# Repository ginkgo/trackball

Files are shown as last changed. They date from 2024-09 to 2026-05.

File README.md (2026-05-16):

# Trackball

## News

- 2026-05-15: Added experimental firmware support for using the trackball as a 3D space mouse. [More info here.](ndof.md)
- 2025-12-25: I'm releasing a new version (Mk.II) that should be easier to print and build.

## Introduction

This is a 3d-printable twist-to-scroll trackball using a Raspberry Pi Pico and two PMW3360 sensors designed using [build123d](https://github.com/gumyr/build123d).

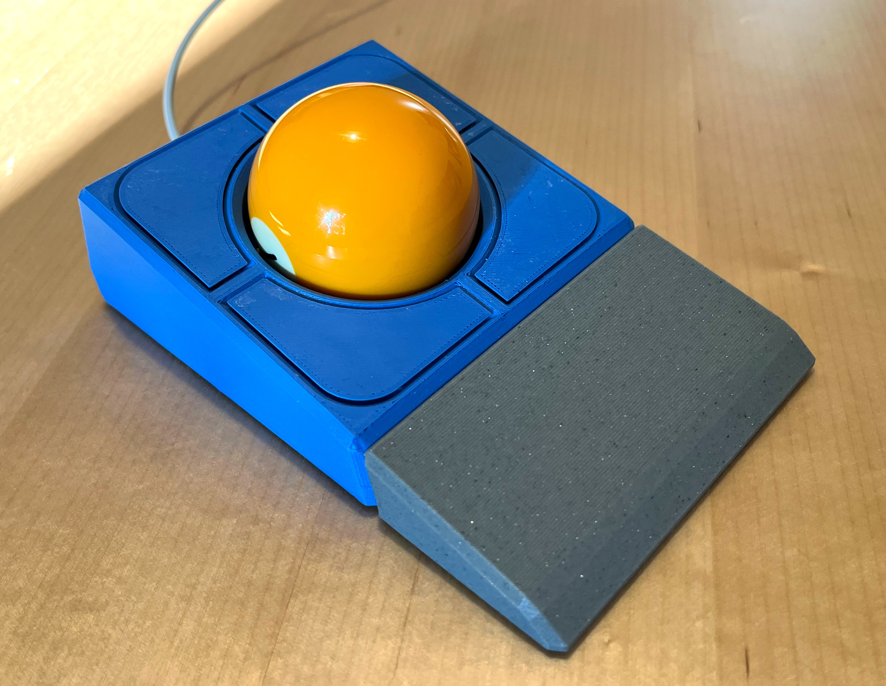
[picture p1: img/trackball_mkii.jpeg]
Trackball Mk.II


## Build Instructions

You can find build instructions for the latest version here: [Mk.II Build Instructions](trackball_mkii.md)

In case you're interested in the original version you can find it [here](trackball_mki.md).

## General Info

It's based on [jfedor2](https://github.com/jfedor2)'s excellent set of projects.
In particular it's using 2 [PMW3360 breakout PCBs](https://github.com/jfedor2/pmw3360-breakout) and 4 [mouse buttons switch mount PCBs](https://github.com/jfedor2/mouse-switch-mount-pcb). It's also using a firmware derived from his [twist-to-scroll trackball](https://github.com/jfedor2/twist-to-scroll-trackball) project.

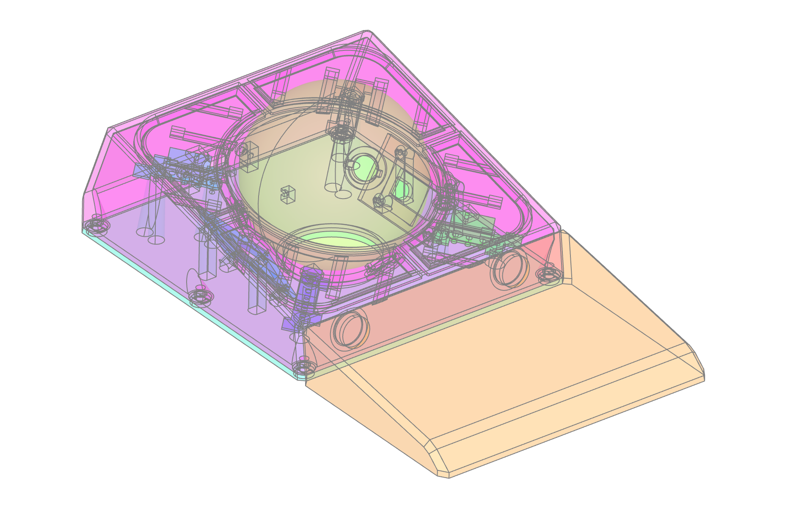
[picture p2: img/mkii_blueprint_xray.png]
Mk.II blueprint


However there's a number of pretty major changes:

Instead of a [RP2040+PMW3360](https://github.com/jfedor2/rp2040-pmw3360) board I'm using a regular Raspberry Pi Pico.

I redesigned the entire enclosure from the ground up in build123d. The nice thing about this is that it should be possible to parameterize the generated model (for instance to use a 55mm trackball instead of a 57.2mm billiards ball or to change the type of bearing used).

The button assembly is quite different and feels a lot better in my opinion.

The sensors are arranged at a 45-degree angle to move them as low as possible and keep them out of the way of the button assembly.
This means when reading from the sensors, some axis values (the X and Z axis) need to be reconstructed from a combination values from both sensors.

This is done in firmware. The basic math isn't too complicated, but it meant that the time delay between reading both sensors should be minimal or else the time lag might show up as unintended twists around the Z axis.
To improve this I interleaved the sensor access. I also switched from RP2040 HW SPI to PIO SPI which allowed for more flexible GPIO mapping.

## Experience

The Mk.II version is significantly easier to build and the button reach and feel is better.
Honestly it's an all-around better design.

<video src="img/mkii_in_action.mp4" width="480" height="480" controls></video>
The Mk.II trackball in action

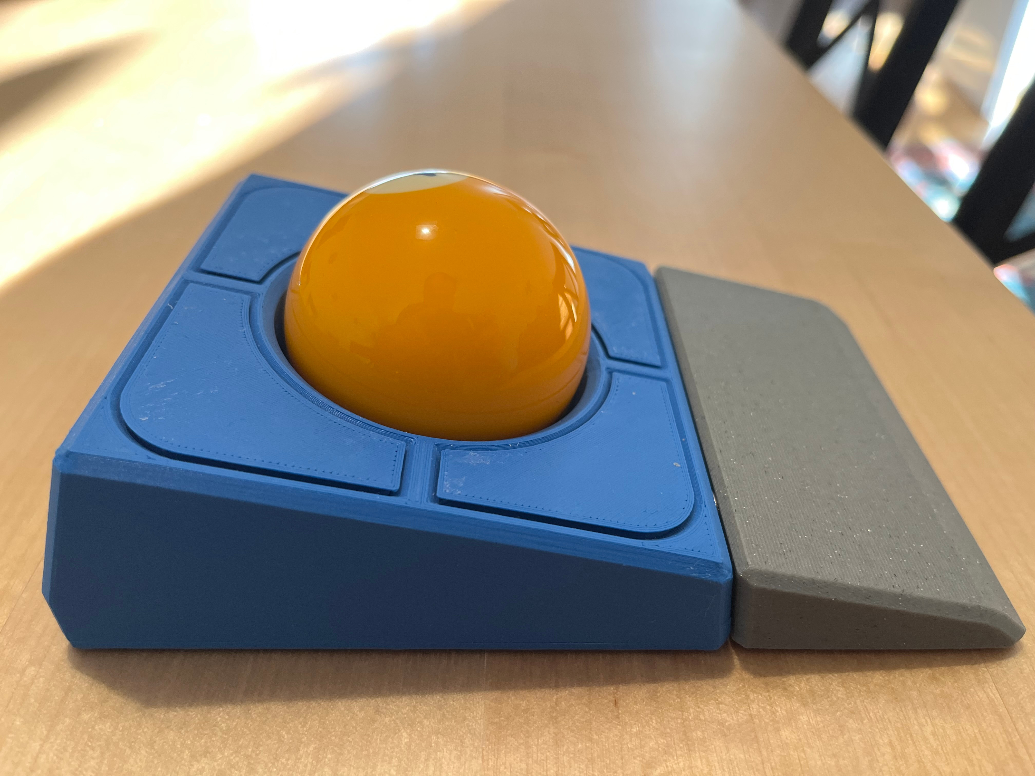
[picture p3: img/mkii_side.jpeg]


## Future Ideas

My next big project will be a combined keyboard+trackball device. This will likely live in a separate github project though.

I'd like to make a magnetically attached top cover for easy transport.

The firmware could need quite a bit of cleanup.
Alternatively adding support for this trackball in QMK might also be an option.
I've created a [rough patch to QMK](https://github.com/ginkgo/qmk_firmware/tree/trackball) but this will need to be reworked to get it merged upstream. It'll also need changes to how sensors are connected to the SoC.

Using PIO it should be possible to access both sensors in perfect lock-step by having them share a single SCLK, NCS, and MOSI pin and having two separate MISO pins that are read at once.

## Support

If you need help with building this then you can reach me on the [/r/trackballs](https://discord.gg/772eGUxAUb) Discord server.
Alternatively you can also create a discussion thread here.

If you have suggestions for improvements feel free to open an issue or create a pull request.

## License

The 3d-printable parts as well as the python code to generate them is copyright 2024-2026 Thomas Weber and licensed under terms the MIT license.

The firmware is copyright 2024-2026 Thomas Weber, copyright 2021 Jacek Fedoryński (jfedor2), and copyright 2019 Ha Thach (tinyusb.org) and licensed under the terms of the MIT license.
There is also a piece of code for the SPI PIO copyright 2020 of the Raspberry Pi that's licensed under the terms of the BSD-3-Clause license.

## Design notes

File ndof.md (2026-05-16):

# Experimental 3D Space Mouse Mode

I recently added support in firmware that allows using the trackball as a space mouse for full 3 axis rotations.

This requires building a separate firmware version for now. In principle it should be possible for one firmware build to support both trackball and space mouse mode and switching between them on the fly but that's not implemented yet.

I've only tested this on Linux with [spacenavd](http://github.com/FreeSpacenav/spacenavd) so far.

## Building the firmware

Follow the general firmware build instructions, but add the `-DDEVICETYPE=SPACEMOUSE` option when configuring.

```
cd firmware
mkdir build
cd build
cmake .. -DBOARD=<board_type> -DTRACKBALL=<trackball_version> -DDEVICETYPE=SPACEMOUSE
make -j8
```

This generates a `trackball.uf2` which you can upload to your board.

## Using the Device

Install `spacenavd` and add the following config option to `/etc/spnavrc`:

```
device-id = cafe:ba3d
```

This is the dummy USB device ID reported by the trackball in spacemouse mode.
Then start the `spacenavd` daemon.

With this any software that supports `libspnav` should now allow you to control rotations using the trackball. I've tested Blender and FreeCAD and they work.
You probably need to tune sensitivity and swap some axes depending on the used application. You can do that with the `spnavcfg` tool.

Blender by default locks the rotation of one axis. To fix this change the 'Orbit Method' from 'Turntable' to 'Trackball' under 'Navigation' in the Preferences.

FreeCAD needs "Swap Y-Z" enabled and RY inverted in spnavcfg. It also needs to have the sensitivity lowered significantly.

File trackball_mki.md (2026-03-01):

# Trackball Mk.I

This is the first version of my DIY trackball. 

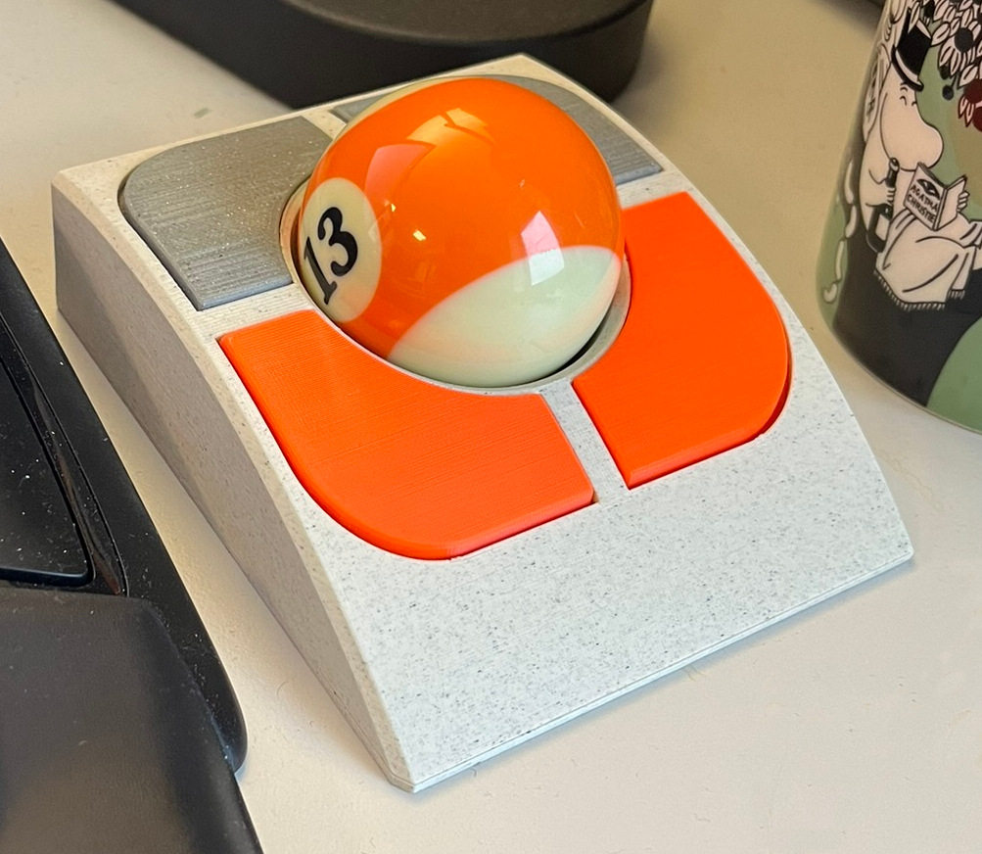
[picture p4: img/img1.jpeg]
Trackball Mk.I


It's significantly different from the second version ([Mk.II](trackball_mkii.md)) which completely redesigned the outer housing.
Personally I think the new version is just overall easier to build and nicer to use but I'm keeping this for posterity.

The old design requires a lot more individual parts that need to be printed and screwed together. On the plus side it's possible to use a regular RaspberryPi Pico board:

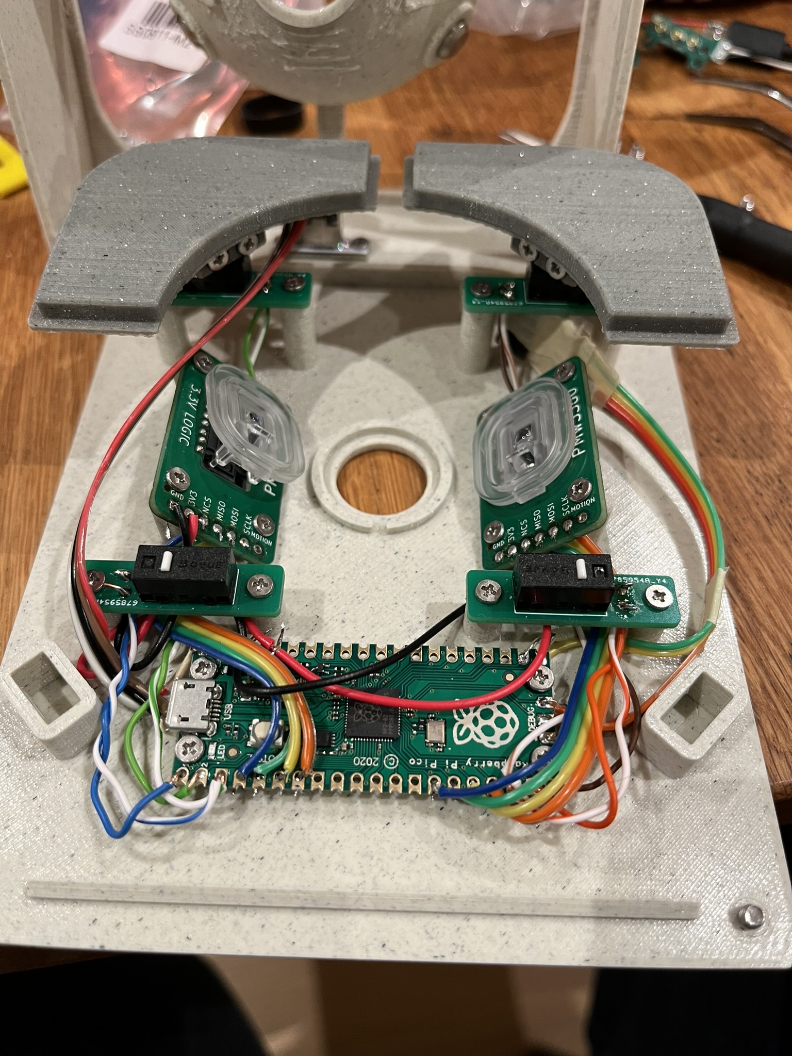
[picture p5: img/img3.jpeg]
opened trackball


## Getting started

You can download tarballs with pregenerated parts and firmware under "Releases". 
If you want to do this yourself you can find details further below.

The Mk.I model allows a bunch of possible configurations regarding what size ball to use and what kind of switch and MCU PCBs to use.

## 3D printing
These are the parts you need to print:

* `bottom`
  * The base plate for the entire assembly. Doesn't need supports.
* `top`
  * The top cover of the trackball. Needs supports.
* `button0`, `button1`, `button2`, `button3`
  * The top buttons. Each one has a different curvature so they're not interchangeable. Need supports.
* `strip0`, `strip1`, `strip2`, `strip3`
  * The flexible springs to hold the button in place. You need 4 of these but they come in identical pairs (two shorter ones for the front and two longer ones for the back). Doesn't need supports when printed on the side.
* `adapter_X.Ymm` (optional)
  * Adapter if you want to use a static bearing to hold the trackball (instead of a BTU)
  * The `X.Ymm` number is the diameter of the bearing. So for instance `adapter_2.5mm` is for 2.5mm bearing balls.

I printed everything with PLA and a layer size of 0.1mm.

The printed models shouldn't need too much cleanup apart from the contact surface between the buttons and the underside of the top cover.
Any residue supports must be removed. I found this area also needs a bit of manual filing and adjustment until the button clickiness feels right.
I used needle files for this.

## Parts

Apart from the 3d-printed parts you need the following:

* 1 microcontroller board. Either:
  * A RaspberryPi Pico
    This should be easy to find but you will need to do some extra soldering for the USB cable.
  * A [RP2040 Supermini](https://www.eelectronicparts.com/products/rp2040-super-mini-pico-compatible-with-raspberry-pi-micro-python-2mb-flash)
    This plugs directly into the USB socket in the back of the trackball so less soldering necessary.
	`--cable-mount-type RP2040_SUPERMINI`
* 2 [PMW3360 breakout PCBs](https://github.com/jfedor2/pmw3360-breakout) with a PMW3360 sensor soldered in.
  These will need to be ordered from a service like JLCPCB or PCBWay. You will find the Gerber files and BOM on jfedor's github.
* 4 keyswitch mount PCBs with a D2F type switch. You have two options here:
  * Custom order jfedor's [mouse switch mount PCB](https://github.com/jfedor2/mouse-switch-mount-pcb)
    `--switch_pcb_type JFEDOR2`
  * Buy 2 pairs of [G304/G305 button replacement PCBs](https://vi.aliexpress.com/item/1005004663221786.html).
    `--switch_pcb_type G304`
* 1 57.2mm billiards ball
  * Or a 55mm trackball if you adjust the ball size in the script
* 3 YK310 type BTUs (or steel/ruby/ceramic bearings with an adapter)
* 4 10x2mm cylindric neodymium magnets (for attaching wrist-rest in Mk.II)
  * The magnets in the main unit can also be thicker
* Machine screws
  * M3x4 (For bottom screws)
  * M2x3 (For almost everything else)
  * M1.6x3 (In case you use G304/G305 button PCBs)
* A [USB-C socket](https://vi.aliexpress.com/item/1005007593502706.html)
  * in case you use a RaspberryPi Pico board.
* Various cabling and solder supplies
  * I recommend getting pairs of JST male/female cables so breakout boards can be attached after soldering.
* Some adhesive rubber feet or strips so the trackball doesn't slip.

## Wiring

Here's some rough wiring diagrams for both board configurations.
You can change the GPIO pins used in `firmware/src/trackball.cc` if you want to move things around.

I recommend using JST cables to connect the microcontroller and the breakout boards.

### Wiring (RaspberryPi Pico)
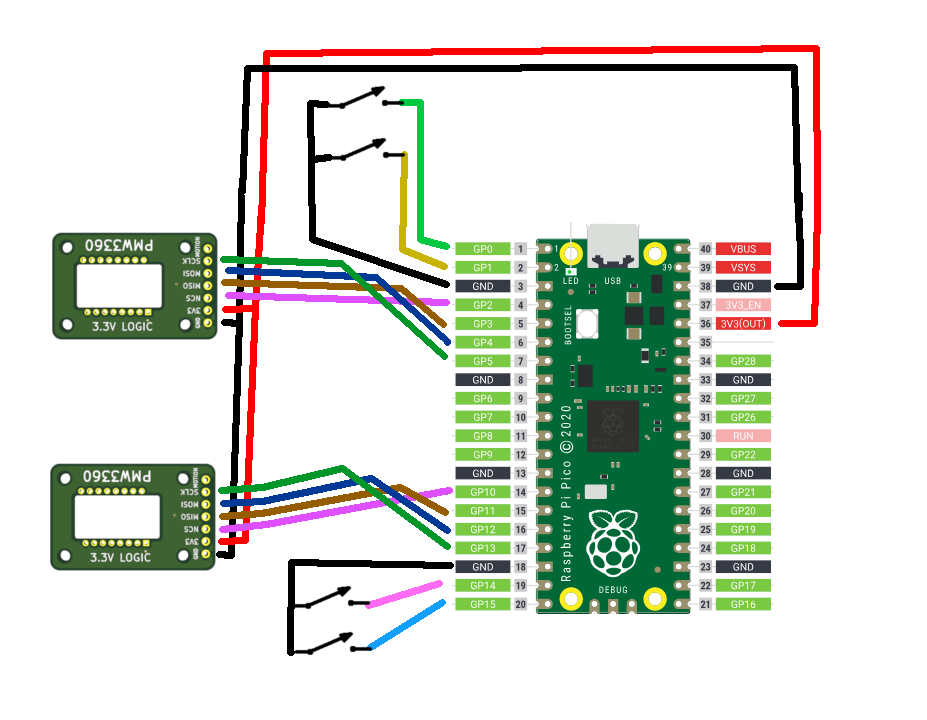
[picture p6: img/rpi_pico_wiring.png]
RaspberryPi Pico wiring diagram


### Wiring (RP2040 Supermini)
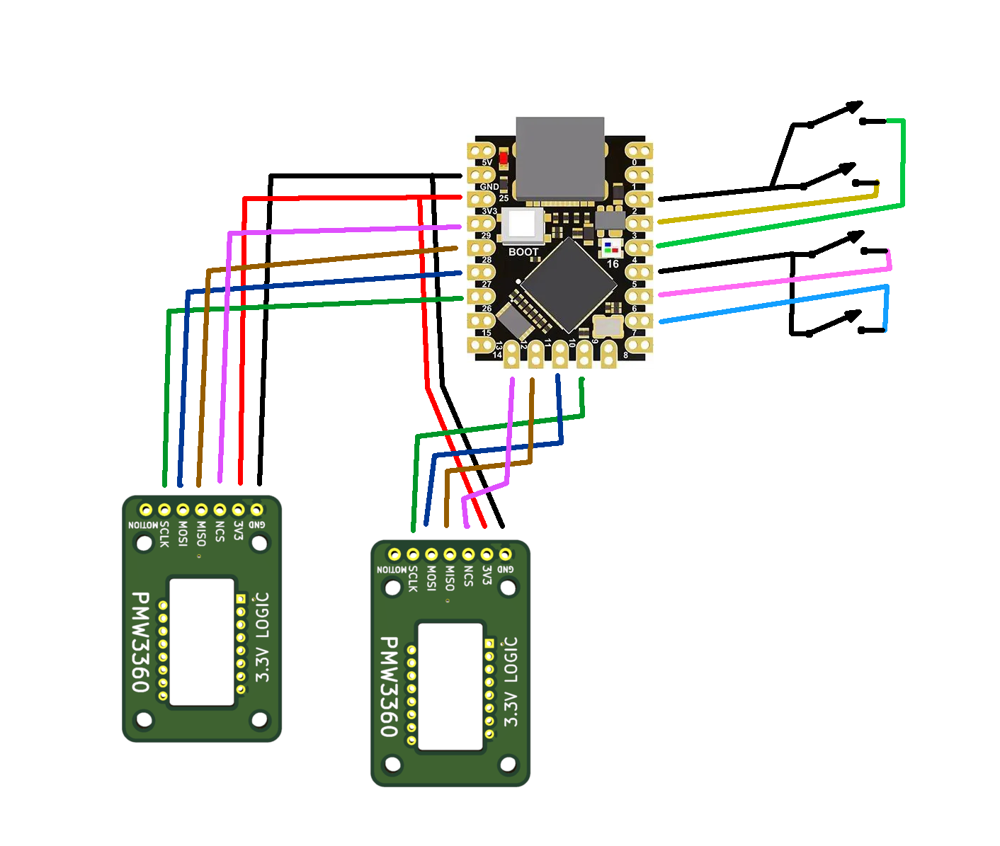
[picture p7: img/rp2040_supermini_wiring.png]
RP2040 Supermini wiring diagram


## Assembly

Once you printed out your parts and wired everything up you should be ready to assemble your trackball.
This should hopefully be relatively straightforward.

* Screw the various boards to the bottom plate.
* Screw flexible strips to the button parts and place the assembled buttons over the switches.
* Place the top part over everything and secure it with the screws on the bottom (and back).
* Push in your bearing of choice.

You can open all the model files in a 3d editor like blender to see where everything goes.

The bit that's probably easiest to mix up is which button goes where. The best way to tell which is which is to look at their curvature. Front buttons have a much steeper angle and the lowest part protudes below the attachment point for the flexible strip.
You should also be able to tell by the layer lines from the 3d print.

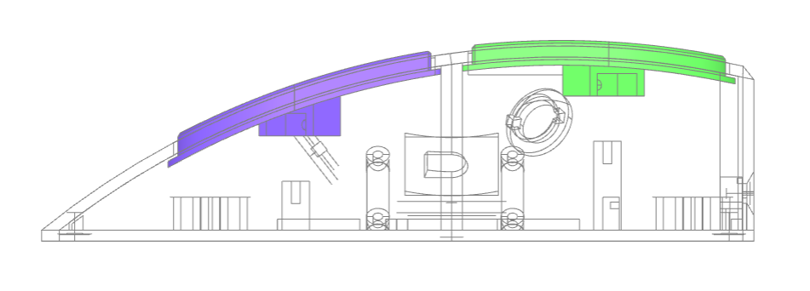
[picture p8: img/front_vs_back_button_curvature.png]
front vs back buttons


## Minor tips and tricks

The trackball can be configured to either use ball transfer units (7.5mm [YK310 or YK311](https://www.aliexpress.com/item/1005005528750648.html) type from aliexpress) or have small indentations to press in small steel or zirconium bearing balls.

However I found it's most flexible to just adapt an enclosure for ball transfer units to bearing balls using a small 3d-printed adapter.

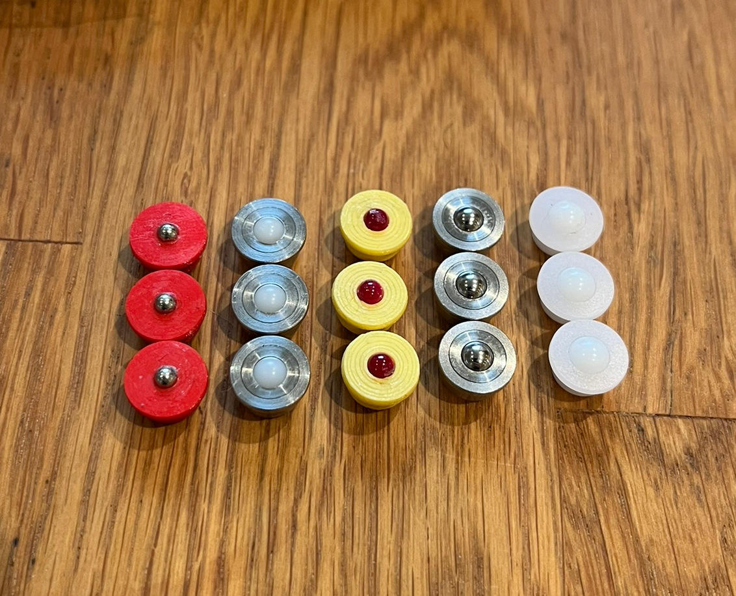
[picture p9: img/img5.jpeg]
different ball transfer units and bearing ball adapters


You can find the pregenerated models for the adapter in the `stl` and `step` folders and the script to generate it in `adapter.py`.

## Experience

I've been using the Mk.I trackball for about a year now. Initially I was kind of struggling finding a type of bearing I like.
At least the cheap BTUs didn't quite feel right. I ended up with using static ruby bearings for my current setup which I tend to like best.
The pool balls I'm using aren't the highest quality and noticeable uneven in places. I should eventually try to get something better. (I ordered a set of Kandy Pearlized balls that got recommended, but these didn't seem to work with my PMW3360 sensors)

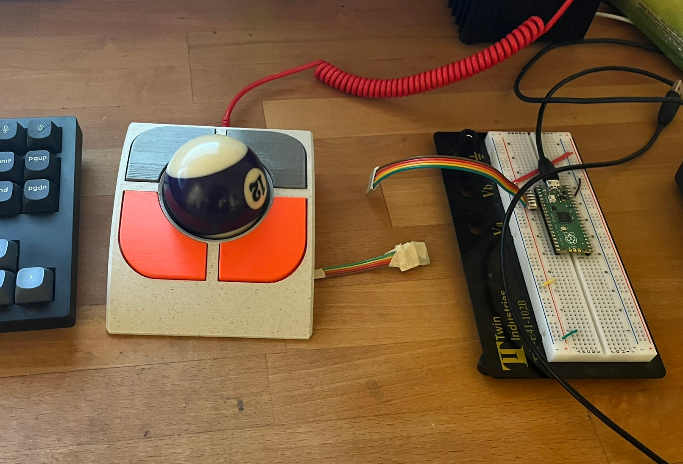
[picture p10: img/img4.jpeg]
my home setup

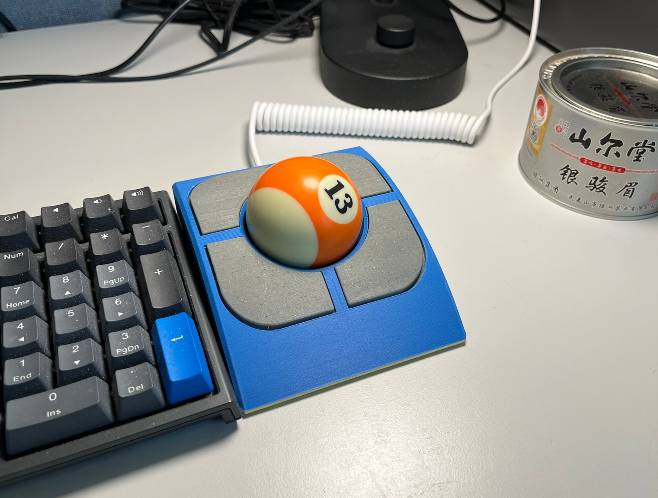
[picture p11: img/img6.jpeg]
my work setup


In principle it should be possible to CNC machine all parts for the Mk.I trackball in metal. (Mk.II is trickier) This would likely need a bit of cleanup to some parts but nothing major.

One persistent problem the Mk.I has is that the front buttons tend to get stuck when you click them. This can be "improved" by filing down the underside of the enclosure, but that leads to loose buttons. Theoretically the proper fix would be to change the angle in which the buttons protrude, but I ended up going for a complete revamp with the Mk.II instead.

## Configuring and generating the models

The enclosure parts are generated by the `trackball.py` script.
They use `build123d` and I generally recommend using `uv` to run them like this:
You can generate the `STL` or `STEP` files by calling

```
$ uv run --with build123d trackball.py --step --outdir mk1
```

This generates `.step` model files in the `mk1` subdir.
You can also use PyPI or Conda to install `build123d` instead.

There's more configuration options. Call the scripts with `--help` for details.

## Building the firmware

To build the firmware you need to have `pico-sdk` installed.
Then configure and build using CMake:

```
cd firmware
mkdir build
cd build
cmake .. -DBOARD=<board_type> -DTRACKBALL=<trackball_version>
make -j8
```

This generates a `trackball.uf2` which you can upload to your board.

`<board_type>` is the type of microcontroller board you want to target. Possible options are `RPI_PICO` for a regular RaspberryPi Pico or `RP2040_SUPERMINI` for a RP2040 supermini board.
`<trackball_version>` is the version of the trackball to generate. This is either `MK_I` for the Mk.I version or `MK_II` for the Mk.II version.

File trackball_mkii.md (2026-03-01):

# Trackball Mk.II

This is the latest version of my DIY trackball. 

Trackball Mk.II

This version is designed so that the entire top assembly including buttons can be printed upside down in one piece. That way what used to be 9 parts that were somewhat fiddly to screw together and assemble are now a single easy to print part.
No support material should be needed for printing either.

Personally I feel like this is the allround better design. Use this unless you really like the look of the old version.

## Getting started

You can download tarballs with pregenerated parts and firmware under "Releases". 
If you want to do this yourself you can find details further below.

## 3D printing
There's only two parts that need to be printed (`bottom` and `top`). The rest are optional.

None should need support materials but a spot or two of organic supports for the openings in the bowl of the `top` part might result in cleaner prints.

* `top`
  * The top cover and button assembly. This should be printed upside-down placed on its flat top surface.
* `bottom`
  * The base plate for the assembly
* `wrist_rest` (optional)
  * This is an optional wrist-rest that attaches to the main unit with neodymium magnets.
* `adapter_X.Ymm` (optional)
  * Adapter if you want to use a static bearing to hold the trackball (instead of a BTU)
  * The `X.Ymm` number is the diameter of the bearing. So for instance `adapter_2.5mm` is for 2.5mm bearing balls.

## Parts

Apart from the 3d-printed parts you need the following:

* A [RP2040 Supermini](https://www.eelectronicparts.com/products/rp2040-super-mini-pico-compatible-with-raspberry-pi-micro-python-2mb-flash)
    This plugs directly into the USB socket in the back of the trackball so less soldering necessary.
* 2 [PMW3360 breakout PCBs](https://github.com/jfedor2/pmw3360-breakout) with a PMW3360 sensor soldered in.
  These will need to be ordered from a service like JLCPCB or PCBWay. You will find the Gerber files and BOM on jfedor's github.
  The 1.9V voltage regulators used in the BOM weren't available when I ordered the boards so I replaced them with pad compatible 2V ones. This is within the allowed voltage range for the PMW3360.
* 4 keyswitch mount PCBs with a D2F type switch.
  * Buy 2 pairs of [G304/G305 button replacement PCBs](https://vi.aliexpress.com/item/1005004663221786.html).
    `--switch_pcb_type G304`
* 1 57.2mm billiards ball
* 3 YK310 type BTUs (or steel/ruby/ceramic bearings with an adapter)
* 4 10x2mm cylindric neodymium magnets
  * The magnets in the main unit can also be thicker
* Machine screws
  * M3x4 (For bottom screws)
  * M2x3 (For almost everything else)
  * M1.6x3 (In case you use G304/G305 button PCBs)
* Various cabling and solder supplies
  * I recommend getting pairs of JST male/female cables so breakout boards can be attached after soldering.
* Some adhesive rubber feet or strips so the trackball doesn't slip.

## Wiring

Here's some rough wiring diagrams for both board configurations.
You can change the GPIO pins used in `firmware/src/trackball.cc` if you want to move things around.

I recommend using JST cables to connect the microcontroller and the breakout boards.

### Wiring
RP2040 Supermini wiring diagram

## Assembly

Once you printed out your parts and wired everything up you should be ready to assemble your trackball.
This should hopefully be relatively straightforward.

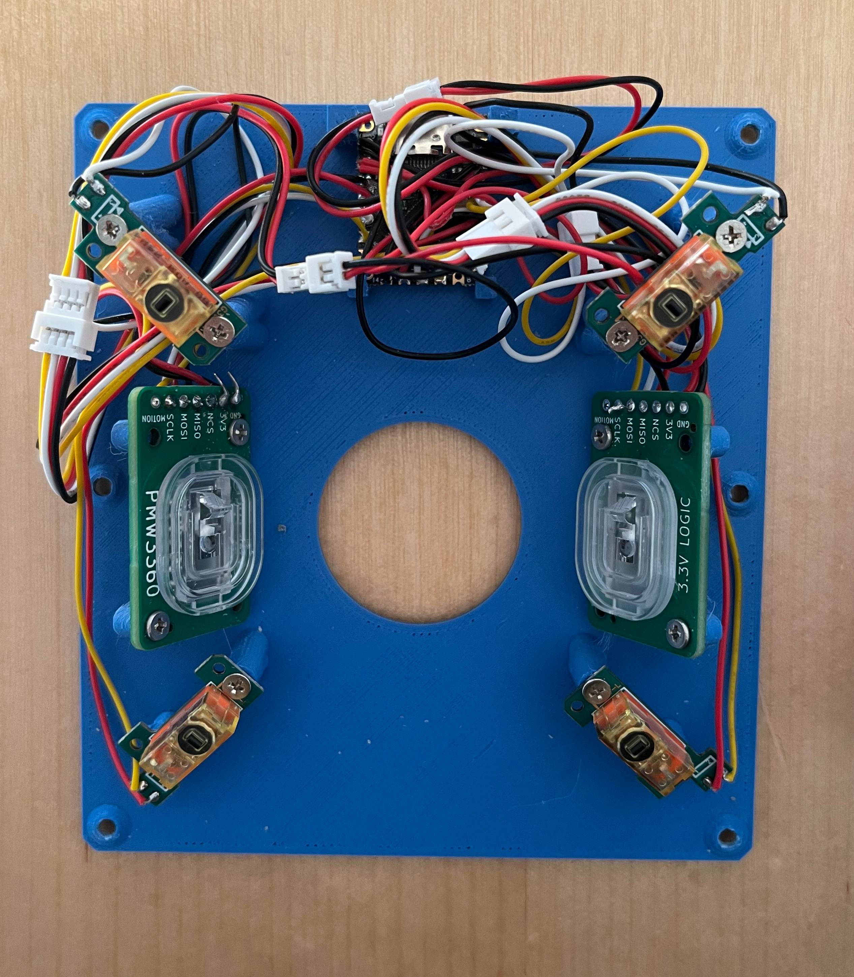
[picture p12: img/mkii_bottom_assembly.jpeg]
Board assembly


* Screw the various boards to the bottom plate.
* Place the top part over everything and secure it with the screws on the bottom (and back).
* Push in your bearing of choice.

You can open all the model files in a 3d editor like blender to see where everything goes.

Depending on your print settings and keyswitches used there may be a tiny bit of wiggle room in the interface between the button pressing pad and the keyswitch. This may result in the button feeling a bit loose and not triggering when pressed on the very edge.

This is somewhat intentional to allow for adjustment. You can tune this by adding a few layers of adhesive tape as shown here:

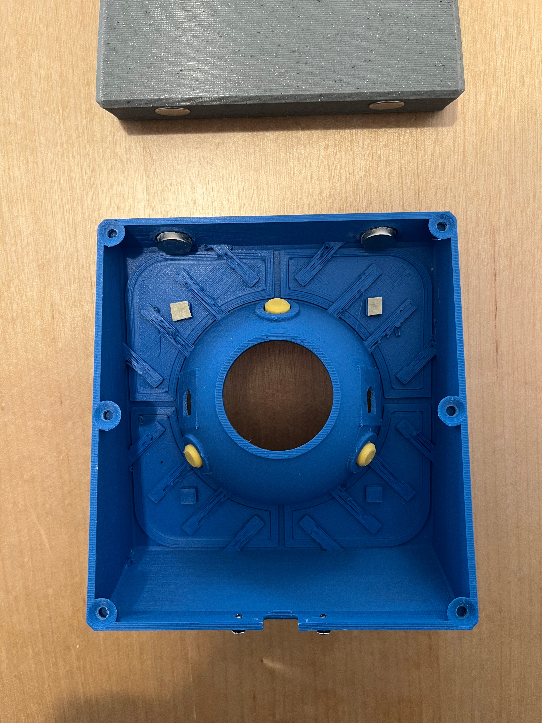
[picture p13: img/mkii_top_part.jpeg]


## Minor tips and tricks

The trackball can be configured to either use ball transfer units (7.5mm [YK310 or YK311](https://www.aliexpress.com/item/1005005528750648.html) type from aliexpress) or have small indentations to press in small steel or zirconium bearing balls.

However I found it's most flexible to just adapt an enclosure for ball transfer units to bearing balls using a small 3d-printed adapter.

different ball transfer units and bearing ball adapters

You can find the pregenerated models for the adapter in the `stl` and `step` folders and the script to generate it in `adapter.py`.

## Experience

The Mk.II version is significantly easier to build and the button reach and feel is better.
Honestly it's an all-around better design.

<video src="img/mkii_in_action.mp4" width="480" height="480" controls></video>
The Mk.II trackball in action

## Configuring and generating the models

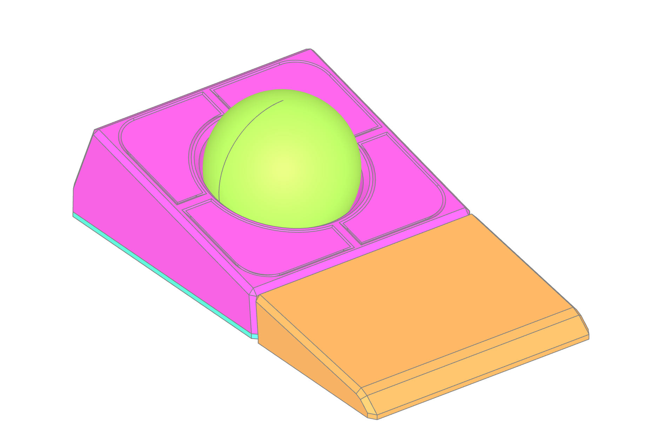
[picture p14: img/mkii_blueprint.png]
Trackball Mk.II blueprint


The enclosure parts are generated by the `trackball2.py` script.
They use `build123d` and I generally recommend using `uv` to run them like this:
You can generate the `STL` or `STEP` files by calling

```
$ uv run --with build123d trackball2.py --step --outdir mk2
```

This generates `.step` model files in the`mk2` subdir.
You can also use PyPI or Conda to install `build123d` instead.

There's more configuration options. Call the scripts with `--help` for details. Most of these are only used by the Mk.I trackball script though.

One config option that is supported is `--split-buttons` that generates separate 1-2 layer fronts for the buttons so you can print them in a different color using a multi-material printer. (or a few manual filament changes).

## Building the firmware

To build the firmware you need to have `pico-sdk` installed.
Then configure and build using CMake:

```
cd firmware
mkdir build
cd build
cmake .. -DBOARD=<board_type> -DTRACKBALL=<trackball_version>
make -j8
```

This generates a `trackball.uf2` which you can upload to your board.

`<board_type>` is the type of microcontroller board you want to target. Possible options are `RPI_PICO` for a regular RaspberryPi Pico or `RP2040_SUPERMINI` for a RP2040 supermini board.
`<trackball_version>` is the version of the trackball to generate. This is either `MK_I` for the Mk.I version or `MK_II` for the Mk.II version.

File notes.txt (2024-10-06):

Notes on partial v1 build (rev 5b054fae645)

Clearances for M2/M3 screws seem spot on. I didn't have any issues.

The button assembly is unstable and has way too much flex perpendicular to hinge.
 * When kept from bending out the top part it seems to be stable -> some extra notches on the underside of the buttons might fix the issue.
The button scratches against the top cover towards the center - more clearance might be necessary

The top cover's alignment notch for the bottom hole doesn't seem to fit.

The ball bearing holes in the cup seem a tiny bit too large (balls fall out, although I guess that could be fixed with a tiny amount of glue)
 - might want to look into replacing these with ball transfer units though

Neodymium magnets work well through 2x2mm PLA so magnetically attached wrist rests should be possible.

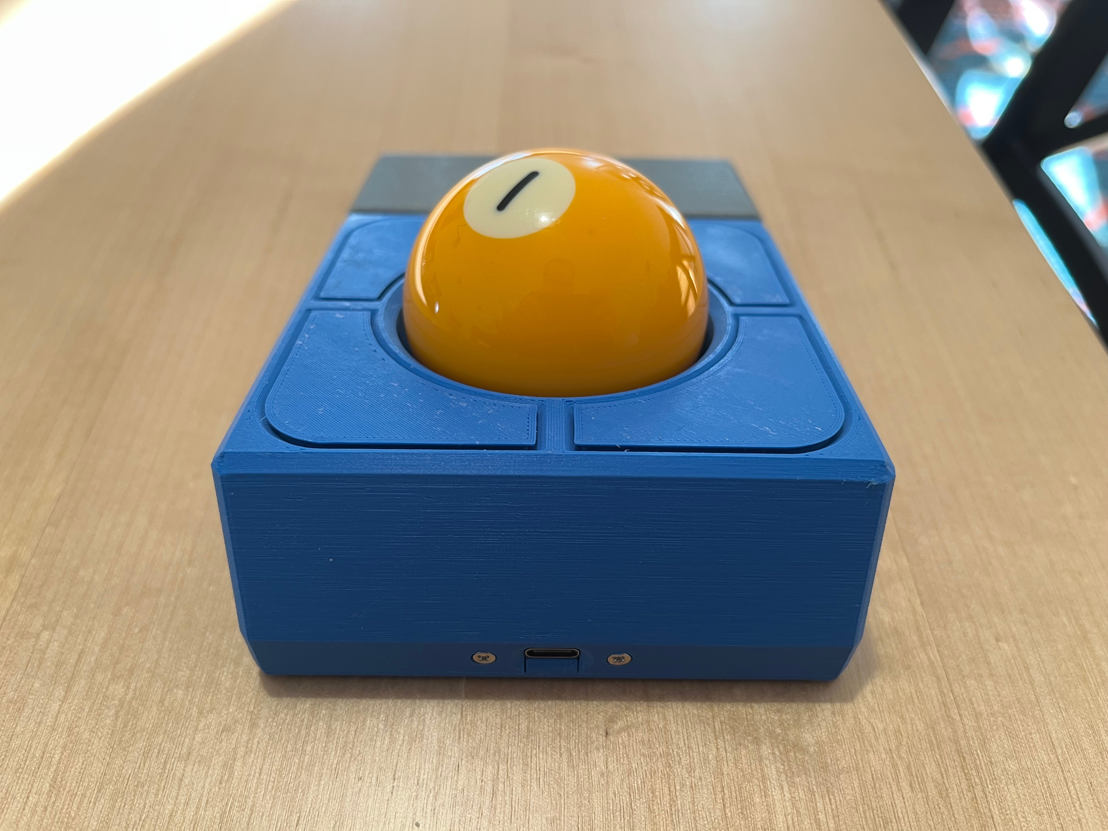
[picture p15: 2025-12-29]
img/mkii_back.jpeg

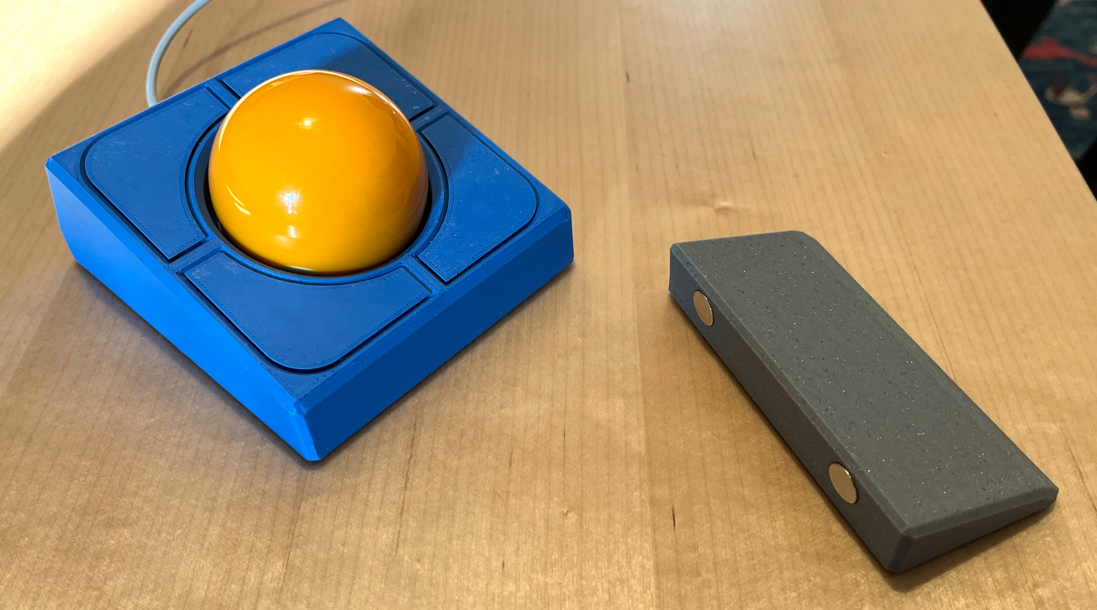
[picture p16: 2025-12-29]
img/mkii_detached2.jpeg

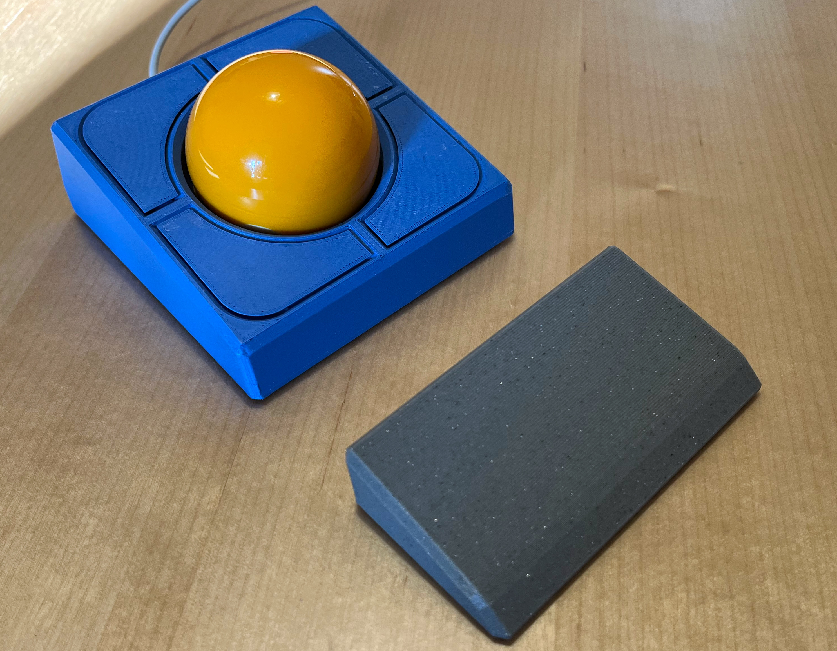
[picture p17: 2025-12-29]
img/mkii_detached.jpeg

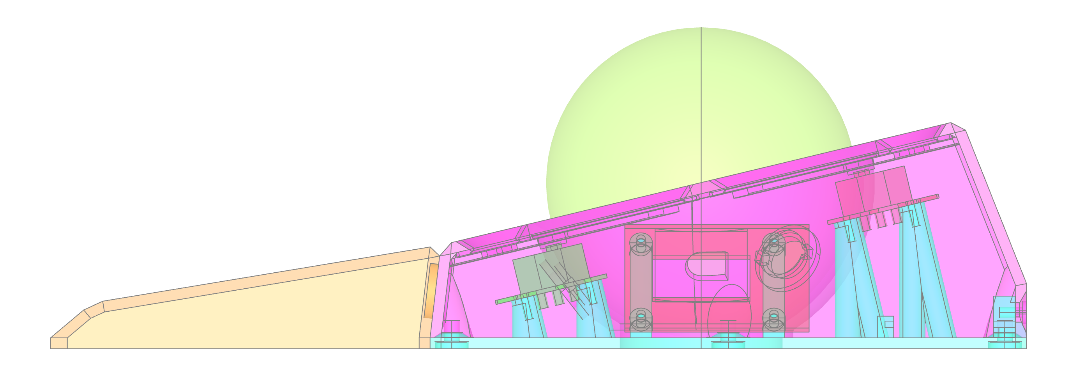
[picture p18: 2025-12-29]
img/mkii_blueprint2.png

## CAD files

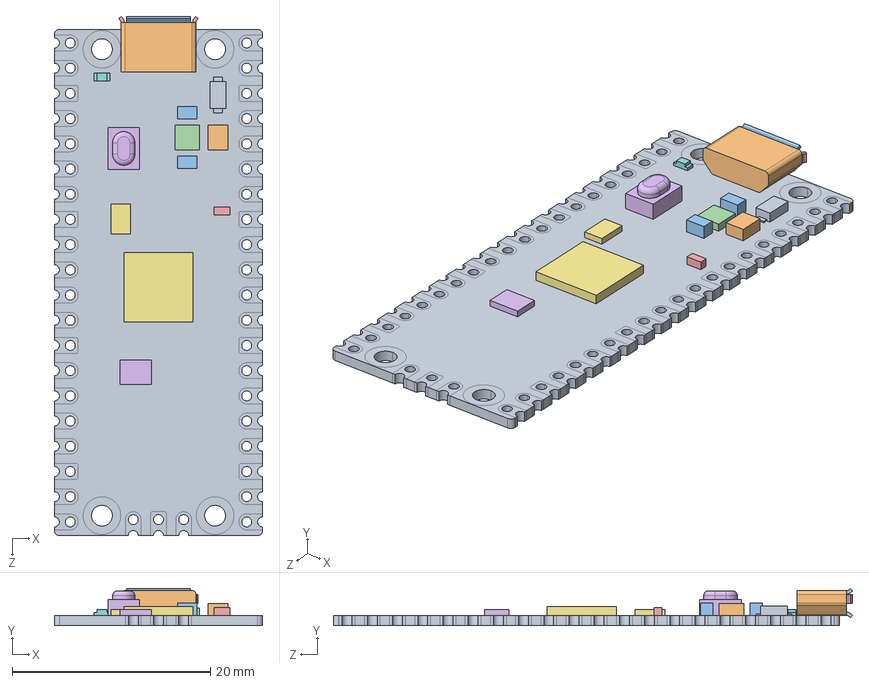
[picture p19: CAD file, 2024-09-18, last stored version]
Pico-R3.step
21.0 x 3.73 x 52.3 mm
PICO_REF_BOARD.STEP
PICO_REF_USB.STEP
PICO_REF_SWITCH.STEP
PICO_REF_MICROCONTROLLER.STEP
PICO_REF_LED.STEP
PICO_REF_ONSEMI.STEP
PICO_BOURNS.STEP
PICO_MURATA.STEP x 2
PICO_RICHTEK.STEP
PICO_DIODES.STEP
PICO_AEL.STEP
PICO_WINBOND.STEP

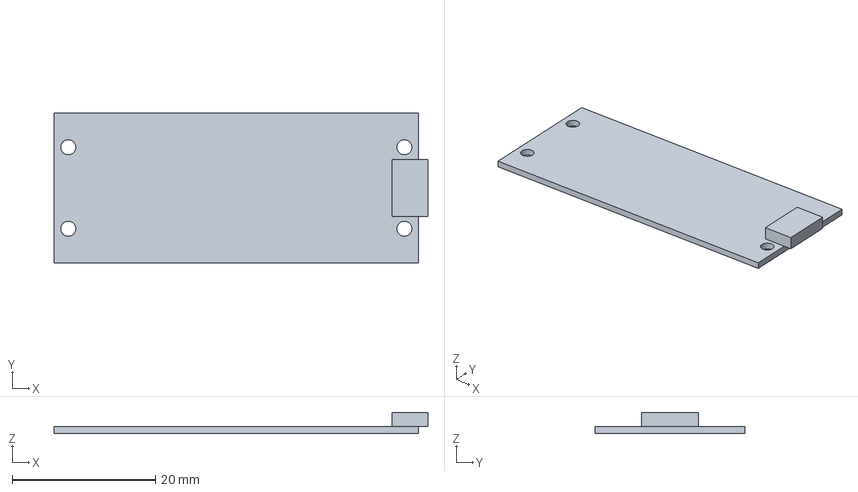
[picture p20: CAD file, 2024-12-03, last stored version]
step/pipico.step
52.3 x 21.0 x 3.00 mm

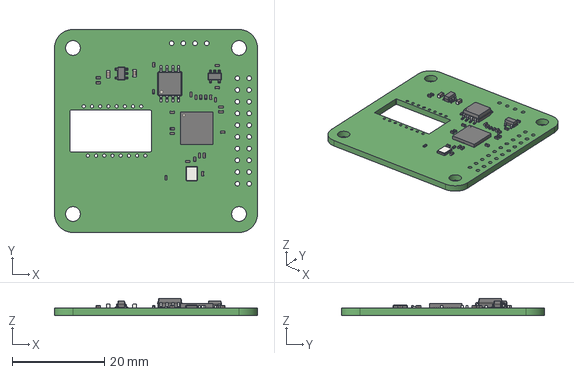
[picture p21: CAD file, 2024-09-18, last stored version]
rp2040-pmw3360.step
44.0 x 44.0 x 3.71 mm

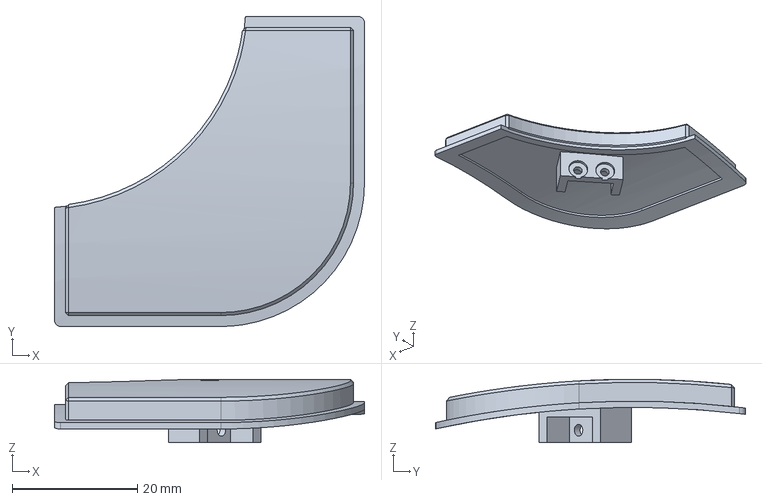
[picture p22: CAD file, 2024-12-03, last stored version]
step/button3.step
49.6 x 49.6 x 10.1 mm

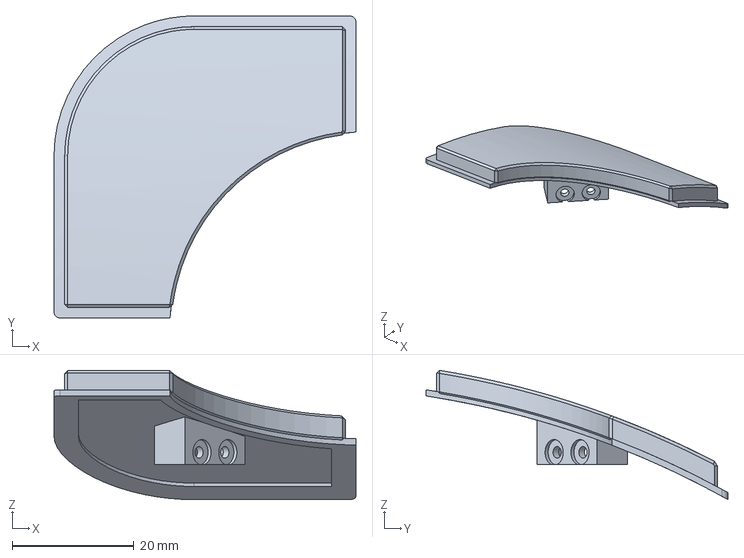
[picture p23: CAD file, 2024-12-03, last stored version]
step/button1.step
49.6 x 49.6 x 21.2 mm

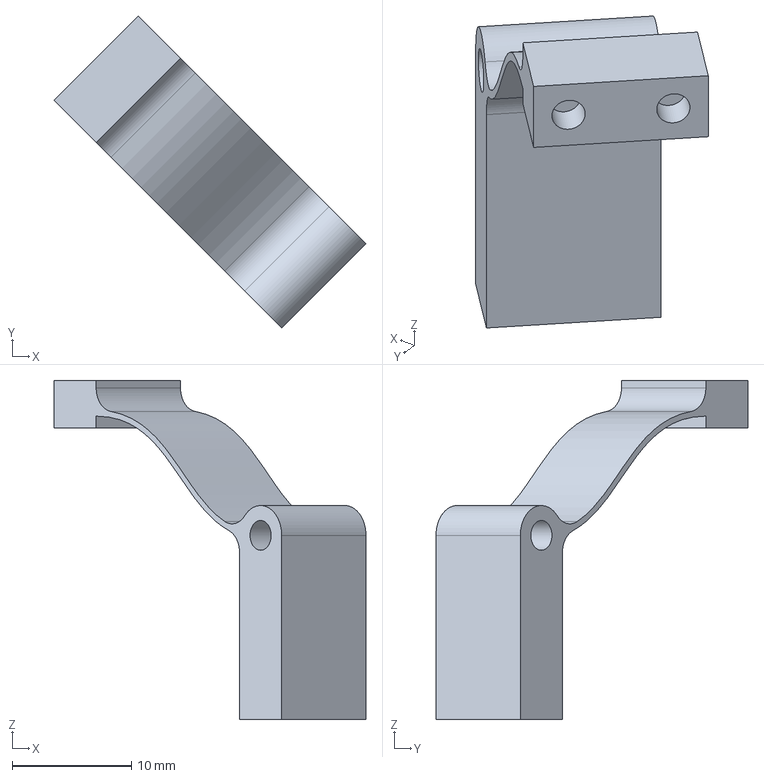
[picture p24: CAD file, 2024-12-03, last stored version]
step/strip3.step
26.2 x 26.2 x 28.5 mm

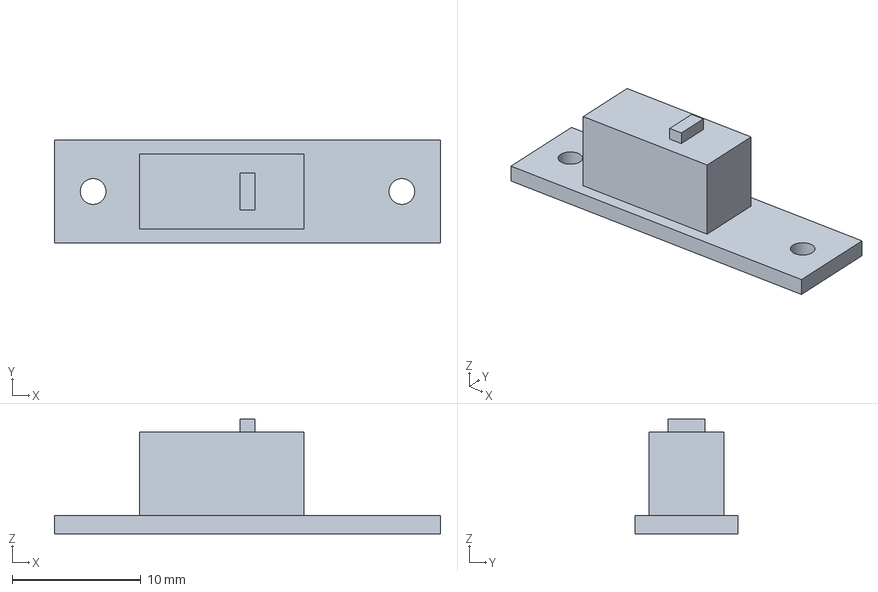
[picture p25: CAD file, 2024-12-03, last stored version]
step/button_pcb0.step
30.0 x 8.00 x 8.90 mm

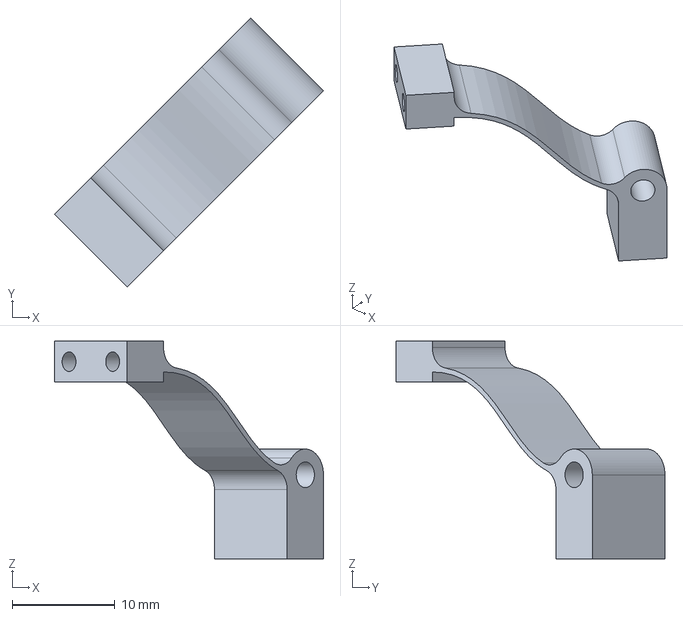
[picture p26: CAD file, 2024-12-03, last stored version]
step/strip0.step
26.2 x 26.2 x 21.2 mm

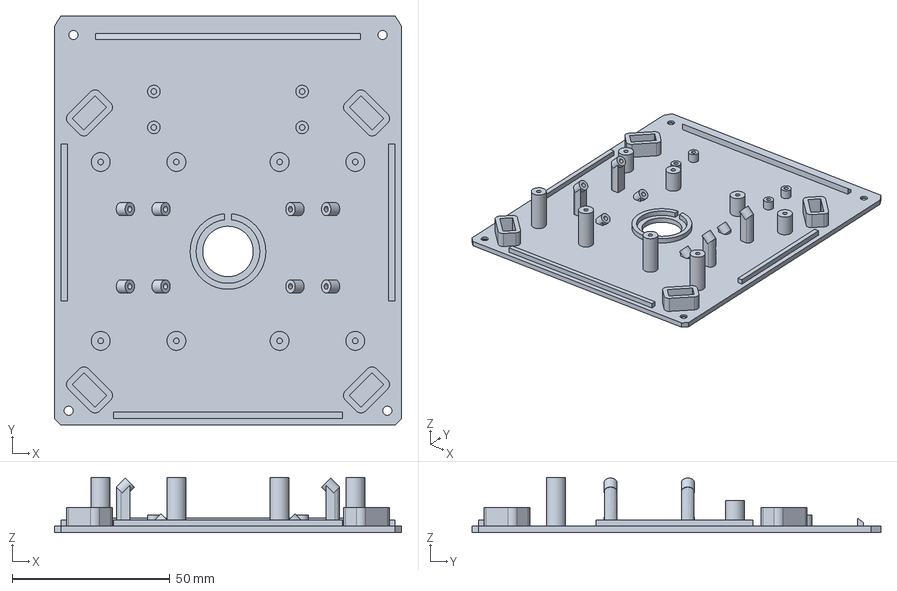
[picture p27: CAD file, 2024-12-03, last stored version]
step/bottom.step
110.0 x 129.6 x 17.5 mm

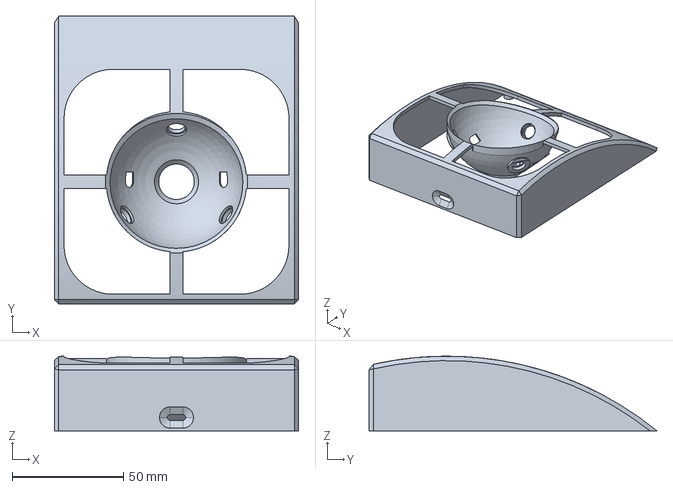
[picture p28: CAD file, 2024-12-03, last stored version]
step/top.step
110.0 x 129.6 x 33.6 mm

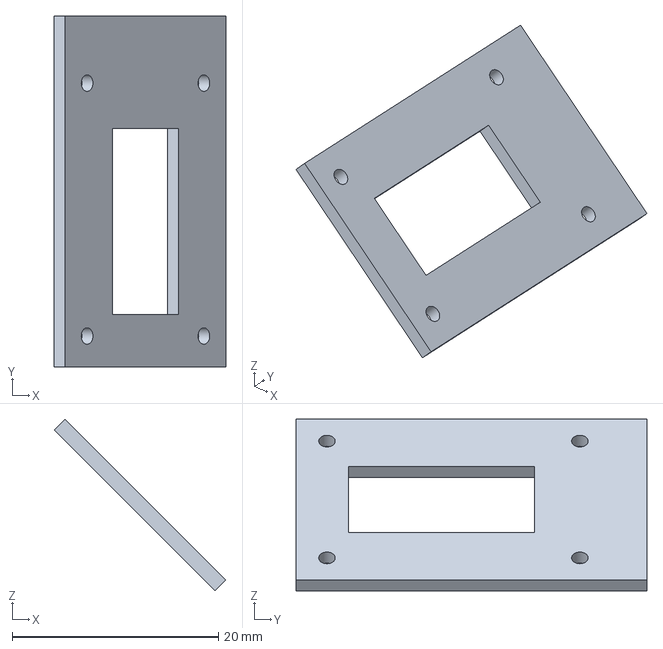
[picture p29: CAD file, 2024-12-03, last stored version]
step/sensor_pcb1.step
16.6 x 34.0 x 16.6 mm

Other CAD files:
step/button2.step
step/strip2.step
step/button_pcb2.step
step/button_pcb1.step
step/button0.step
step/strip1.step
step/adapter.step
step/button_pcb3.step
step/sensor_pcb2.step
stl/adapter.stl
stl/ball.stl
stl/bottom.stl
stl/button0.stl
stl/button1.stl
stl/button2.stl
stl/button3.stl
stl/button_pcb0.stl
stl/button_pcb1.stl
stl/button_pcb2.stl
stl/button_pcb3.stl
stl/pipico.stl
stl/sensor_pcb1.stl
stl/sensor_pcb2.stl
stl/strip0.stl
stl/strip1.stl
stl/strip2.stl
stl/strip3.stl
stl/top.stl

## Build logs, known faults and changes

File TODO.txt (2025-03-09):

Adjust screw-holes on the bottom sides to use M2(or maybe M3?) screws instead M1.6.
Fix front-button angling issue

Add QMK support

Fuse the PIO
Clean up firmware configuration

use build123d assembly to put everything together
split bowl part from top  and add extra attachment points to bottom
Add requirements.txt
Make options configurable from commandline args

magnetically attached wrist-rest

Change geometry so front buttons are less inclined
Change sensor angles to lower ball further

Move USB-C mount pcb to bottom part (and reinforce)

magnetic cover
sapphire/glass/CaF2 window to protect sensors from dust

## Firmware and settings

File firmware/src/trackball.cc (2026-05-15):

/*
 * The MIT License (MIT)
 *
 * Copyright (c) 2021 Jacek Fedorynski
 * Copyright (c) 2019 Ha Thach (tinyusb.org)
 *
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
 */

#include <math.h>
#include <stdio.h>
#include <stdlib.h>
#include <string.h>

#include <bsp/board.h>
#include <tusb.h>

#include <pico/bootrom.h>
#include <pico/stdlib.h>

#include <hardware/flash.h>
#include <hardware/gpio.h>

#include "crc.h"
#include "pmw3360.h"

extern "C" {
#include "pio_spi.h"
}

// These IDs are bogus. If you want to distribute any hardware using this,
// you will have to get real ones.
#define USB_VID 0xCAFE
#if POINTING_DEVICE
#define USB_PID 0xBADA
#elif SPACEMOUSE
#define USB_PID 0xBA3D
#else
#error unknown device type
#endif

#define CONFIG_VERSION 1
#define CONFIG_SIZE 26

#define NSENSORS 2
#define NBUTTONS 4

#define PRESUMED_FLASH_SIZE 2097152
#define CONFIG_OFFSET_IN_FLASH (PRESUMED_FLASH_SIZE - FLASH_SECTOR_SIZE)
#define FLASH_CONFIG_IN_MEMORY (((uint8_t*) XIP_BASE) + CONFIG_OFFSET_IN_FLASH)

#define SENSOR0_PIO pio0
#define SENSOR1_PIO pio1
#define SENSOR0_SM 0
#define SENSOR1_SM 1

#if RPI_PICO
uint button_pins[NBUTTONS] = { 0, 14, 1, 15};

#define SENSOR0_NCS 10
#define SENSOR0_MISO 11
#define SENSOR0_MOSI 12
#define SENSOR0_SCK 13

#define SENSOR1_NCS 2
#define SENSOR1_MISO 3
#define SENSOR1_MOSI 4
#define SENSOR1_SCK 5
#elif RP2040_SUPERMINI

#if TRACKBALL_MK_II
uint button_pins[NBUTTONS] = { 7, 4, 6, 3};
#else
uint button_pins[NBUTTONS] = { 6, 3, 7, 4};
#endif

// GPIO pins to pull down so we can use them as extra GND pins
#define NGND_PINS 2
uint gnd_pins[NGND_PINS] = {2, 5};

#define SENSOR0_NCS 13
#define SENSOR0_MISO 12
#define SENSOR0_MOSI 11
#define SENSOR0_SCK 10

#define SENSOR1_NCS 29
#define SENSOR1_MISO 28
#define SENSOR1_MOSI 27
#define SENSOR1_SCK 26

#else
#error Unknown board configuration.
#endif

PMW3360_pair sensors(
	{{SENSOR0_PIO, SENSOR0_SM}, SENSOR0_MISO, SENSOR0_MOSI, SENSOR0_SCK, SENSOR0_NCS},
	{{SENSOR1_PIO, SENSOR1_SM}, SENSOR1_MISO, SENSOR1_MOSI, SENSOR1_SCK, SENSOR1_NCS});

tusb_desc_device_t const desc_device = {
	.bLength = sizeof(tusb_desc_device_t),
	.bDescriptorType = TUSB_DESC_DEVICE,
	.bcdUSB = 0x0200,
	.bDeviceClass = 0x00,
	.bDeviceSubClass = 0x00,
	.bDeviceProtocol = 0x00,
	.bMaxPacketSize0 = CFG_TUD_ENDPOINT0_SIZE,

	.idVendor = USB_VID,
	.idProduct = USB_PID,
	.bcdDevice = 0x0100,

	.iManufacturer = 0x01,
	.iProduct = 0x02,
	.iSerialNumber = 0x00,

	.bNumConfigurations = 0x01,
};

#if POINTING_DEVICE
uint8_t const desc_hid_report[] = {
	0x05, 0x01,			// Usage Page (Generic Desktop Ctrls)
	0x09, 0x02,			// Usage (Mouse)
	0xA1, 0x01,			// Collection (Application)
	0x05, 0x01,			//	 Usage Page (Generic Desktop Ctrls)
	0x09, 0x02,			//	 Usage (Mouse)
	0xA1, 0x02,			//	 Collection (Logical)
	0x85, 0x01,			//	   Report ID (1)
	0x09, 0x01,			//	   Usage (Pointer)
	0xA1, 0x00,			//	   Collection (Physical)
	0x05, 0x09,			//		 Usage Page (Button)
	0x19, 0x01,			//		 Usage Minimum (0x01)
	0x29, 0x08,			//		 Usage Maximum (0x08)
	0x95, 0x08,			//		 Report Count (8)
	0x75, 0x01,			//		 Report Size (1)
	0x25, 0x01,			//		 Logical Maximum (1)
	0x81, 0x02,			//		 Input (Data,Var,Abs,No Wrap,Linear,Preferred State,No Null Position)
	0x05, 0x01,			//		 Usage Page (Generic Desktop Ctrls)
	0x09, 0x30,			//		 Usage (X)
	0x09, 0x31,			//		 Usage (Y)
	0x95, 0x02,			//		 Report Count (2)
	0x75, 0x10,			//		 Report Size (16)
	0x16, 0x00, 0x80,	//		 Logical Minimum (-32768)
	0x26, 0xFF, 0x7F,	//		 Logical Maximum (32767)
	0x81, 0x06,			//		 Input (Data,Var,Rel,No Wrap,Linear,Preferred State,No Null Position)
	0xA1, 0x02,			//		 Collection (Logical)
	0x85, 0x02,			//		   Report ID (2)
	0x09, 0x48,			//		   Usage (Resolution Multiplier)
	0x95, 0x01,			//		   Report Count (1)
	0x75, 0x02,			//		   Report Size (2)
	0x15, 0x00,			//		   Logical Minimum (0)
	0x25, 0x01,			//		   Logical Maximum (1)
	0x35, 0x01,			//		   Physical Minimum (1)
	0x45, 0x78,			//		   Physical Maximum (120)
	0xB1, 0x02,			//		   Feature (Data,Var,Abs,No Wrap,Linear,Preferred State,No Null Position,Non-volatile)
	0x85, 0x01,			//		   Report ID (1)
	0x09, 0x38,			//		   Usage (Wheel)
	0x35, 0x00,			//		   Physical Minimum (0)
	0x45, 0x00,			//		   Physical Maximum (0)
	0x16, 0x00, 0x80,	//		   Logical Minimum (-32768)
	0x26, 0xFF, 0x7F,	//		   Logical Maximum (32767)
	0x75, 0x10,			//		   Report Size (16)
	0x81, 0x06,			//		   Input (Data,Var,Rel,No Wrap,Linear,Preferred State,No Null Position)
	0xC0,				//		 End Collection
	0xA1, 0x02,			//		 Collection (Logical)
	0x85, 0x02,			//		   Report ID (2)
	0x09, 0x48,			//		   Usage (Resolution Multiplier)
	0x75, 0x02,			//		   Report Size (2)
	0x15, 0x00,			//		   Logical Minimum (0)
	0x25, 0x01,			//		   Logical Maximum (1)
	0x35, 0x01,			//		   Physical Minimum (1)
	0x45, 0x78,			//		   Physical Maximum (120)
	0xB1, 0x02,			//		   Feature (Data,Var,Abs,No Wrap,Linear,Preferred State,No Null Position,Non-volatile)
	0x35, 0x00,			//		   Physical Minimum (0)
	0x45, 0x00,			//		   Physical Maximum (0)
	0x75, 0x04,			//		   Report Size (4)
	0xB1, 0x03,			//		   Feature (Const,Var,Abs,No Wrap,Linear,Preferred State,No Null Position,Non-volatile)
	0x85, 0x01,			//		   Report ID (1)
	0x05, 0x0C,			//		   Usage Page (Consumer)
	0x16, 0x00, 0x80,	//		   Logical Minimum (-32768)
	0x26, 0xFF, 0x7F,	//		   Logical Maximum (32767)
	0x75, 0x10,			//		   Report Size (16)
	0x0A, 0x38, 0x02,	//		   Usage (AC Pan)
	0x81, 0x06,			//		   Input (Data,Var,Rel,No Wrap,Linear,Preferred State,No Null Position)
	0xC0,				//		 End Collection
	0xC0,				//	   End Collection
	0xC0,				//	 End Collection
	0x06, 0x00, 0xFF,	//	 Usage Page (Vendor Defined 0xFF00)
	0x09, 0x20,			//	 Usage (0x20)
	0x85, 0x03,			//	 Report ID (3)
	0x75, 0x08,			//	 Report Size (8)
	0x95, CONFIG_SIZE,	//	 Report Count (CONFIG_SIZE)
	0xB1, 0x02,			//	 Feature (Data,Var,Abs,No Wrap,Linear,Preferred State,No Null Position,Non-volatile)
	0xC0,				// End Collection
};
#elif SPACEMOUSE
uint8_t const desc_hid_report[] = {
	0x05, 0x01,         // Usage Page (Generic Desktop)
	0x09, 0x08,         // Usage (Multi-Axis Controller)
	0xA1, 0x01,         // Collection (Application)
	0x85, 0x01,         //  Report ID (1)
	0x05, 0x09,         //  Usage Page (Button)
	0x19, 0x01,         //  Usage Minimum (0x01)
	0x29, 0x08,         //  Usage Maximum (0x08)
	0x95, 0x08,         //  Report Count (8)
	0x75, 0x01,         //  Report Size (1)
	0x25, 0x01,         //  Logical Maximum (1)
	0x81, 0x02,         //  Input (Data,Var,Abs,No Wrap,Linear,Preferred State,No Null Position)
	0x05, 0x01,         //  Usage Page (Generic Desktop)
	0x09, 0x30,         //  Usage (X)
	0x09, 0x31,         //  Usage (Y)
	0x09, 0x32,         //  Usage (Z)
	0x09, 0x33,         //  Usage (Rx)
	0x09, 0x34,         //  Usage (Ry)
	0x09, 0x35,         //  Usage (Rz)
	0x75, 0x10,         //  Report Size (16)
	0x95, 0x06,         //  Report Count (6)
	0x16, 0x00, 0x80,   //  Logical Minimum (-32768)
	0x26, 0xFF, 0x7F,   //  Logical Maximum (32767)
	0x81, 0x06,         //  Input (Data,Var,Rel,No Wrap,Linear,Preferred State,No Null Position)
	0xC0,               // End Collection
};
#endif

#define CONFIG_TOTAL_LEN (TUD_CONFIG_DESC_LEN + TUD_HID_DESC_LEN)
#define EPNUM_HID 0x81

uint8_t const desc_configuration[] = {
	// Config number, interface count, string index, total length, attribute, power in mA
	TUD_CONFIG_DESCRIPTOR(1, 1, 0, CONFIG_TOTAL_LEN, 0, 100),

	// Interface number, string index, protocol, report descriptor len, EP In address, size & polling interval
	TUD_HID_DESCRIPTOR(0, 0, HID_ITF_PROTOCOL_NONE, sizeof(desc_hid_report), EPNUM_HID, CFG_TUD_HID_EP_BUFSIZE, 1)
};

char const* string_desc_arr[] = {
	(const char[]){ 0x09, 0x04 },  // 0: is supported language is English (0x0409)
	"ginkgo",       			   // 1: Manufacturer
#if POINTING_DEVICE
	"trackball",				   // 2: Product
#elif SPACEMOUSE
	"spacemouse",				   // 2: Product
#endif
};

#if POINTING_DEVICE
struct __attribute__((packed)) hid_report_t {
	uint8_t buttons;
	int16_t dx;
	int16_t dy;
	int16_t vwheel;
	int16_t hwheel;
};

hid_report_t report;

enum class ButtonFunction : int8_t {
	NO_FUNCTION = 0,
	BUTTON1 = 1,
	BUTTON2 = 2,
	BUTTON3 = 3,
	BUTTON4 = 4,
	BUTTON5 = 5,
	BUTTON6 = 6,
	BUTTON7 = 7,
	BUTTON8 = 8,
	CLICK_DRAG = 9,
	SHIFT = 10,
};

enum class SensorFunction : int8_t {
	NO_FUNCTION = 0,
	CURSOR_X = 1,
	CURSOR_Y = 2,
	VERTICAL_SCROLL = 3,
	HORIZONTAL_SCROLL = 4,
	CURSOR_X_INVERTED = -1,
	CURSOR_Y_INVERTED = -2,
	VERTICAL_SCROLL_INVERTED = -3,
	HORIZONTAL_SCROLL_INVERTED = -4,
};

enum class ConfigCommand : int8_t {
	NO_COMMAND = 0,
	RESET_INTO_BOOTSEL = 1,
};

struct __attribute__((packed)) config_t {
	uint8_t version;
	ConfigCommand command;
	SensorFunction sensor_function[NSENSORS][2];
	SensorFunction sensor_shifted_function[NSENSORS][2];
	uint8_t sensor_cpi[NSENSORS];
	uint8_t sensor_shifted_cpi[NSENSORS];
	ButtonFunction button_function[NBUTTONS];
	ButtonFunction button_shifted_function[NBUTTONS];
	uint32_t crc32;
};

config_t config = {
	.version = CONFIG_VERSION,
	.command = ConfigCommand::NO_COMMAND,
	.sensor_function = {
		{ SensorFunction::CURSOR_X, SensorFunction::CURSOR_Y_INVERTED },
		{ SensorFunction::VERTICAL_SCROLL, SensorFunction::NO_FUNCTION },
	},
	.sensor_shifted_function = {
		{ SensorFunction::CURSOR_X, SensorFunction::CURSOR_Y_INVERTED },
		{ SensorFunction::VERTICAL_SCROLL, SensorFunction::NO_FUNCTION },
	},
	.sensor_cpi = {
		10000 / 100,
		10000 / 100,
	},
	.sensor_shifted_cpi = {
		10000 / 100,
		10000 / 100,
	},
	.button_function = {
		ButtonFunction::BUTTON1,
		ButtonFunction::BUTTON2,
		ButtonFunction::BUTTON3,
		ButtonFunction::BUTTON4,
	},
	.button_shifted_function = {
		ButtonFunction::BUTTON1,
		ButtonFunction::BUTTON2,
		ButtonFunction::BUTTON3,
		ButtonFunction::BUTTON4,
	},
	.crc32 = 0,
};

uint8_t resolution_multiplier = 0;

int accumulated_scroll[NSENSORS][2] = { 0 };
uint64_t last_scroll_timestamp[NSENSORS][2] = { 0 };
uint32_t prev_pin_state = 0xffffffff;
bool click_drag = false;
uint8_t current_cpi[NSENSORS] = { 0 };
bool scroll_mode = false;
bool not_scroll_mode = false;
float running_avg_x = 0;
float running_avg_y = 0;
float running_avg_hscroll = 0;
float running_avg_vscroll = 0;

#define ABS(x) (x > 0 ? x : -x)

int16_t handle_scroll(int sensor, int axis, int16_t movement, uint8_t multiplier_mask, float* running_avg_scroll) {
	int16_t ret = 0;
	*running_avg_scroll += 0.1 * movement / current_cpi[sensor];
	if (resolution_multiplier & multiplier_mask) {
		ret = movement;
	} else {
		if (movement != 0) {
			last_scroll_timestamp[sensor][axis] = time_us_64();
			accumulated_scroll[sensor][axis] += movement;
			int ticks = accumulated_scroll[sensor][axis] / 120;
			accumulated_scroll[sensor][axis] -= ticks * 120;
			ret = ticks;
		} else {
			if ((accumulated_scroll[sensor][axis] != 0) &&
				(time_us_64() - last_scroll_timestamp[sensor][axis] > 1000000)) {
				accumulated_scroll[sensor][axis] = 0;
			}
		}
	}
	return ret;
}

#elif SPACEMOUSE
struct __attribute__((packed)) hid_report_t {
	uint8_t buttons;
	int16_t x;
	int16_t y;
	int16_t z;
	int16_t rx;
	int16_t ry;
	int16_t rz;
};

hid_report_t report;
#endif /* POINTING_DEVICE */

#if POINTING_DEVICE
bool hid_pointing_task() {
	if (!tud_hid_ready()) {
		return false;
	}

	memset(&report, 0, sizeof(report));

	uint32_t pin_state = gpio_get_all();

	bool shifted = false;

	// first pass to determine if we're in shifted state
	for (int i = 0; i < NBUTTONS; i++) {
		if (config.button_function[i] == ButtonFunction::SHIFT &&
			!(pin_state & (1 << button_pins[i]))) {
			shifted = true;
		}
	}

	// set CPI if not already correct
	uint8_t wanted_cpi = shifted ? config.sensor_shifted_cpi[0] : config.sensor_cpi[0];
	if (current_cpi[0] != wanted_cpi && wanted_cpi >= 1 && wanted_cpi <= 120) {
		sensors.set_cpi(wanted_cpi * 100);
		current_cpi[0] = wanted_cpi;
	}

	for (int i = 0; i < NBUTTONS; i++) {
		ButtonFunction button_function =
			shifted ? config.button_shifted_function[i] : config.button_function[i];
		if (config.button_function[i] == ButtonFunction::SHIFT) {
			button_function = ButtonFunction::NO_FUNCTION;
		}
		switch (button_function) {
		case ButtonFunction::NO_FUNCTION:
		case ButtonFunction::SHIFT:
			break;
		case ButtonFunction::BUTTON1:
		case ButtonFunction::BUTTON2:
		case ButtonFunction::BUTTON3:
		case ButtonFunction::BUTTON4:
		case ButtonFunction::BUTTON5:
		case ButtonFunction::BUTTON6:
		case ButtonFunction::BUTTON7:
		case ButtonFunction::BUTTON8: {
			int button = static_cast<int>(button_function) - 1;
			if (!(pin_state & (1 << button_pins[i]))) {
				report.buttons |= 1 << button;
			}
			break;
		}
		case ButtonFunction::CLICK_DRAG:
			if ((prev_pin_state & (1 << button_pins[i])) &&
				!(pin_state & (1 << button_pins[i]))) {
				click_drag = !click_drag;
			}
			break;
		}
	}

	if (click_drag) {
		report.buttons |= 1 << 0;
	}

	prev_pin_state = pin_state;

	running_avg_x *= 0.9;
	running_avg_y *= 0.9;
	running_avg_vscroll *= 0.9;
	running_avg_hscroll *= 0.9;

	sensors.update();

#if TRACKBALL_MK_I
	// 45 degree angle -> 1/sqrt(2) factor
	double movement_x = 		   (sensors.movement[0][0] + sensors.movement[1][0]) / 2.0;
	double movement_y = ((sensors.movement[0][1] + sensors.movement[1][1]) * 0.7071067811865475);
	double movement_z = ((sensors.movement[0][1] - sensors.movement[1][1]) * 0.7071067811865475);
#elif TRACKBALL_MK_II
	// 60 degree angle -> 2*1/2 factor (inverted)
	double movement_x =  -(sensors.movement[0][0] + sensors.movement[1][0]) / 2.0;
	double movement_y =  -(sensors.movement[0][1] + sensors.movement[1][1]);
	double movement_z =	 -(sensors.movement[0][1] - sensors.movement[1][1]);
#else
#error Unknown Trackball
#endif

	if (ABS(movement_y) + ABS(movement_x) > ABS(movement_z) * 0.5) {
		movement_z = 0;
	} else {
		movement_x = 0;
		movement_y = 0;
	}

	movement_x *= 0.1;
	movement_y *= 0.1;
	movement_z *= 0.2;

	running_avg_x += 0.1 * movement_x / current_cpi[0];
	running_avg_y += 0.1 * movement_y / current_cpi[0];

	static double residual_x = 0;
	static double residual_y = 0;
	static double residual_z = 0;

	movement_x += residual_x;
	movement_y += residual_y;
	movement_z += residual_z;

	report.dx	  -= (int16_t)round(movement_x);
	report.dy	  += (int16_t)round(movement_y);
	report.vwheel += handle_scroll(0,0, (int16_t)round(movement_z), 1<<0, &running_avg_vscroll);

	residual_x = movement_x - round(movement_x);
	residual_y = movement_y - round(movement_y);
	residual_z = movement_z - round(movement_z);

	tud_hid_report(1, &report, sizeof(report));

	return true;
}
#endif /* POINTING_DEVICE */

#if SPACEMOUSE
bool hid_spacemouse_task() {
	if (!tud_hid_ready()) {
		return false;
	}

	memset(&report, 0, sizeof(report));
	static bool cpi_set = false;
	if (!cpi_set) {
		sensors.set_cpi(12000);
		cpi_set = true;
	}

	sensors.update();

#if TRACKBALL_MK_I
	// 45 degree angle -> 1/sqrt(2) factor
	double movement_x = 		   (sensors.movement[0][0] + sensors.movement[1][0]) / 2.0;
	double movement_y = ((sensors.movement[0][1] + sensors.movement[1][1]) * 0.7071067811865475);
	double movement_z = ((sensors.movement[0][1] - sensors.movement[1][1]) * 0.7071067811865475);
#elif TRACKBALL_MK_II
	// 60 degree angle -> 2*1/2 factor (inverted)
	double movement_x =  -(sensors.movement[0][0] + sensors.movement[1][0]) / 2.0;
	double movement_y =  -(sensors.movement[0][1] + sensors.movement[1][1]);
	double movement_z =	 -(sensors.movement[0][1] - sensors.movement[1][1]);
#else
#error Unknown Trackball
#endif

	movement_x *= 6.0;
	movement_y *= 6.0;
	movement_z *= 6.0;

	static double residual_x = 0;
	static double residual_y = 0;
	static double residual_z = 0;

	movement_x += residual_x * 0.9;
	movement_y += residual_y * 0.9;
	movement_z += residual_z * 0.9;

	report.x = 0;
	report.y = 0;
	report.z = 0;
	report.rx = (int16_t)round(movement_y);
	report.ry = (int16_t)round(movement_z);
	report.rz = (int16_t)round(movement_x)*-1;

	residual_x = movement_x - round(movement_x);
	residual_y = movement_y - round(movement_y);
	residual_z = movement_z - round(movement_z);

	tud_hid_report(1, &report, sizeof(report));

	return true;
}
#endif

void pin_init(uint pin) {
	gpio_init(pin);
	gpio_set_dir(pin, GPIO_IN);
	gpio_pull_up(pin);
}

void pins_init() {

#if RP2040_SUPERMINI
	for (int i = 0; i < NGND_PINS; ++i) {
		// Pull to GND
		gpio_init(gnd_pins[i]);
		gpio_set_dir(gnd_pins[i], GPIO_OUT);
		gpio_put(gnd_pins[i], 0);
	}
#endif

	for (int i = 0; i < NBUTTONS; i++) {
		pin_init(button_pins[i]);
	}
}

void sensors_init() {
	sensors.init();
}

#if POINTING_DEVICE
void run_config_command() {
	// we probably shouldn't do this for config read from flash
	// or let's just not write any non-null command to flash
	if (config.command == ConfigCommand::RESET_INTO_BOOTSEL) {
		reset_usb_boot(0, 0);
	}
}

bool checksum_ok(const uint8_t* buffer) {
	return crc32(buffer, CONFIG_SIZE - 4) == ((config_t*) buffer)->crc32;
}

bool version_ok(const uint8_t* buffer) {
	return ((config_t*) buffer)->version == CONFIG_VERSION;
}

void load_config() {
	if (checksum_ok(FLASH_CONFIG_IN_MEMORY) && version_ok(FLASH_CONFIG_IN_MEMORY)) {
		memcpy(&config, FLASH_CONFIG_IN_MEMORY, CONFIG_SIZE);
	}
}

void persist_config() {
	uint8_t buffer[FLASH_PAGE_SIZE];
	memset(buffer, 0, sizeof(buffer));
	memcpy(buffer, &config, CONFIG_SIZE);
	uint32_t ints = save_and_disable_interrupts();
	flash_range_erase(CONFIG_OFFSET_IN_FLASH, FLASH_SECTOR_SIZE);
	flash_range_program(CONFIG_OFFSET_IN_FLASH, buffer, FLASH_PAGE_SIZE);
	restore_interrupts(ints);
}
#endif /* POINTING_DEVICE */

int main() {
	// Use GPIO 16&17 for serial
	gpio_set_function(16, GPIO_FUNC_UART); //TX
	gpio_set_function(17, GPIO_FUNC_UART); //RX

	stdio_init_all();
	board_init();
#if POINTING_DEVICE
	load_config();
#endif /* POINTING_DEVICE */
	pins_init();
	sensors_init();

	tusb_init();

	int count = 0;
	uint64_t start = to_us_since_boot(get_absolute_time());
	while (true) {
		tud_task();	 // tinyusb device task
#if POINTING_DEVICE
		bool did_sensor_reading = hid_pointing_task();
#elif SPACEMOUSE
		bool did_sensor_reading = hid_spacemouse_task();
#endif

		if (did_sensor_reading) {
			count++;
		}

		if (count == 1000) {
			uint64_t end = to_us_since_boot(get_absolute_time());
			uint64_t diff_us = end-start;

			printf("%.2f Hz sampling\n", 1000.0f / ( diff_us / 1000000.0));

			count = 0;
			start = end;
		}
	}

	return 0;
}

// Invoked when device is mounted
void tud_mount_cb() {
	// reset hi-res scroll for when we reboot from Windows into Linux
	//resolution_multiplier = 0;
}

// Invoked when received GET DEVICE DESCRIPTOR
// Application return pointer to descriptor
uint8_t const* tud_descriptor_device_cb() {
	return (uint8_t const*) &desc_device;
}

// Invoked when received GET HID REPORT DESCRIPTOR
// Application return pointer to descriptor
// Descriptor contents must exist long enough for transfer to complete
uint8_t const* tud_hid_descriptor_report_cb(uint8_t itf) {
	return desc_hid_report;
}

// Invoked when received GET_REPORT control request
// Application must fill buffer report's content and return its length.
// Return zero will cause the stack to STALL request
uint16_t tud_hid_get_report_cb(uint8_t itf, uint8_t report_id, hid_report_type_t report_type, uint8_t* buffer, uint16_t reqlen) {
#if POINTING_DEVICE
	if (report_id == 2 && reqlen >= 1) {
		memcpy(buffer, &resolution_multiplier, 1);
		return 1;
	}
	if (report_id == 3 && reqlen >= CONFIG_SIZE) {
		config.crc32 = crc32((uint8_t*) &config, CONFIG_SIZE - 4);
		memcpy(buffer, &config, CONFIG_SIZE);
		return CONFIG_SIZE;
	}
#endif /* POINTING_DEVICE */

	return 0;
}

// Invoked when received SET_REPORT control request or
// received data on OUT endpoint ( Report ID = 0, Type = 0 )
void tud_hid_set_report_cb(uint8_t itf, uint8_t report_id, hid_report_type_t report_type, uint8_t const* buffer, uint16_t bufsize) {
#if POINTING_DEVICE
	if (report_id == 2 && bufsize >= 1) {
		memcpy(&resolution_multiplier, buffer, 1);
	}
	if (report_id == 3 && bufsize >= CONFIG_SIZE) {
		if (checksum_ok(buffer) && version_ok(buffer)) {
			memcpy(&config, buffer, CONFIG_SIZE);
			run_config_command();
			persist_config();
		}
	}
#endif /* POINTING_DEVICE */
}

// Invoked when received GET CONFIGURATION DESCRIPTOR
// Application return pointer to descriptor
// Descriptor contents must exist long enough for transfer to complete
uint8_t const* tud_descriptor_configuration_cb(uint8_t index) {
	return desc_configuration;
}

static uint16_t _desc_str[32];

// Invoked when received GET STRING DESCRIPTOR request
// Application return pointer to descriptor, whose contents must exist long enough for transfer to complete
uint16_t const* tud_descriptor_string_cb(uint8_t index, uint16_t langid) {
	uint8_t chr_count;

	if (index == 0) {
		memcpy(&_desc_str[1], string_desc_arr[0], 2);
		chr_count = 1;
	} else {
		// Note: the 0xEE index string is a Microsoft OS 1.0 Descriptors.
		// https://docs.microsoft.com/en-us/windows-hardware/drivers/usbcon/microsoft-defined-usb-descriptors

		if (!(index < sizeof(string_desc_arr) / sizeof(string_desc_arr[0])))
			return NULL;

		const char* str = string_desc_arr[index];

		// Cap at max char
		chr_count = strlen(str);
		if (chr_count > 31)
			chr_count = 31;

		// Convert ASCII string into UTF-16
		for (uint8_t i = 0; i < chr_count; i++) {
			_desc_str[1 + i] = str[i];
		}
	}

	// first byte is length (including header), second byte is string type
	_desc_str[0] = (TUSB_DESC_STRING << 8) | (2 * chr_count + 2);

	return _desc_str;
}

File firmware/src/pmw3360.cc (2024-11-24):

// derived from https://github.com/mrjohnk/PMW3360DM-T2QU

#include <pico/stdlib.h>
#include <hardware/gpio.h>

#include "pmw3360.h"

#include "registers.h"
#include "srom.h"

extern "C" {
#include <stdio.h>
#include "pio_spi.h"
}

void PMW3360_pair::init() {

	for (uint8_t i = 0; i < 2; ++i)
	{
		gpio_set_function(sensors[i].sck_pin, GPIO_FUNC_NULL);
		gpio_init(sensors[i].ncs_pin);
		gpio_set_dir(sensors[i].ncs_pin, GPIO_OUT);
		gpio_put(sensors[i].ncs_pin, 1);

		gpio_function_t pio_func = ((sensors[i].spi.pio) == pio0 ?
									GPIO_FUNC_PIO0 : GPIO_FUNC_PIO1);
		gpio_set_function(sensors[i].sck_pin, pio_func);
		gpio_set_function(sensors[i].mosi_pin, pio_func);
		gpio_set_function(sensors[i].miso_pin, pio_func);

		uint offset = pio_add_program(sensors[i].spi.pio, &spi_cpha1_program);

		float clkdiv = 62.5f/2; /* 500KHz @ 125 clk_sys */
		bool cpha = 1;
		bool cpol = 1;
		pio_spi_init(sensors[i].spi.pio, sensors[i].spi.sm,
					 offset, 8, clkdiv, cpha, cpol,
					 sensors[i].sck_pin,
					 sensors[i].mosi_pin,
					 sensors[i].miso_pin);
	}

	perform_startup();
}

void PMW3360_pair::set_cpi(unsigned int cpi) {
	int cpival = (cpi / 100) - 1;
	write_register(Config1, cpival);
}

void PMW3360_pair::update() {
	// write 0x01 to Motion register and read from it to freeze the motion values and make them available
	write_register(Motion, 0x01);

	uint8_t v[2];
	read_registers(Motion, v);
	is_on_surface = !((v[0] | v[1]) & (1 << 3));

	read_registers(Delta_X_L, v);
	movement[0][0] = v[0];
	movement[1][0] = v[1];

	read_registers(Delta_X_H, v);
	movement[0][0] |= ((int16_t) v[0]) << 8;
	movement[1][0] |= ((int16_t) v[1]) << 8;

	read_registers(Delta_Y_L, v);
	movement[0][1] = v[0];
	movement[1][1] = v[1];

	read_registers(Delta_Y_H, v);
	movement[0][1] |= ((int16_t) v[0]) << 8;
	movement[1][1] |= ((int16_t) v[1]) << 8;
}

void PMW3360_pair::cs_select(uint8_t sensor) {
	asm volatile("nop \n nop \n nop");
	gpio_put(sensors[sensor].ncs_pin, 0);  // Active low
	asm volatile("nop \n nop \n nop");
}

void PMW3360_pair::cs_deselect(uint8_t sensor) {
	asm volatile("nop \n nop \n nop");
	gpio_put(sensors[sensor].ncs_pin, 1);
	asm volatile("nop \n nop \n nop");
}

void PMW3360_pair::read_registers(uint8_t reg_addr, uint8_t (&v)[2]) {
	cs_select(0);
	cs_select(1);

	// send adress of the register, with MSBit = 0 to indicate it's a read
	uint8_t x = reg_addr & 0x7f;
	pio_spi_write8_blocking(&sensors[0].spi, &x, 1);
	pio_spi_write8_blocking(&sensors[1].spi, &x, 1);
	sleep_us(100);	// tSRAD
	// read data
	pio_spi_read8_blocking(&sensors[0].spi, &v[0], 1);
	pio_spi_read8_blocking(&sensors[1].spi, &v[1], 1);

	sleep_us(1);  // tSCLK-NCS for read operation is 120ns
	cs_deselect(0);
	cs_deselect(1);
	sleep_us(19);  // tSRW/tSRR (=20us) minus tSCLK-NCS
}

void PMW3360_pair::write_register(uint8_t reg_addr, uint8_t data) {
	cs_select(0);
	cs_select(1);

	// send adress of the register, with MSBit = 1 to indicate it's a write
	uint8_t x = reg_addr | 0x80;
	pio_spi_write8_blocking(&sensors[0].spi, &x, 1);
	pio_spi_write8_blocking(&sensors[1].spi, &x, 1);

	// send data
	pio_spi_write8_blocking(&sensors[0].spi, &data, 1);
	pio_spi_write8_blocking(&sensors[1].spi, &data, 1);

	sleep_us(20);  // tSCLK-NCS for write operation
	cs_deselect(0);
	cs_deselect(1);
	sleep_us(100);	// tSWW/tSWR (=120us) minus tSCLK-NCS. Could be shortened, but is looks like a safe lower bound
}


void PMW3360_pair::perform_startup() {
	for (uint8_t i=0; i < 2; ++i)
	{
		cs_deselect(i);						   // ensure that the serial port is reset
		cs_select(i);						   // ensure that the serial port is reset
		cs_deselect(i);						   // ensure that the serial port is reset
	}

	write_register(Power_Up_Reset, 0x5a);  // force reset
	sleep_ms(50);						   // wait for it to reboot

	// read registers 0x02 to 0x06 (and discard the data)
	uint8_t v[2];
	read_registers(Motion, v);
	read_registers(Delta_X_L, v);
	read_registers(Delta_X_H, v);
	read_registers(Delta_Y_L, v);
	read_registers(Delta_Y_H, v);

	// upload the firmware
	upload_firmware();
	sleep_ms(10);
}

void PMW3360_pair::upload_firmware() {
	// send the firmware to the chip, cf p.18 of the datasheet

	// Write 0 to Rest_En bit of Config2 register to disable Rest mode.
	write_register(Config2, 0x20);

	// write 0x1d in SROM_enable reg for initializing
	write_register(SROM_Enable, 0x1d);

	// wait for more than one frame period
	sleep_ms(10);  // assume that the frame rate is as low as 100fps... even if it should never be that low

	// write 0x18 to SROM_enable to start SROM download
	write_register(SROM_Enable, 0x18);

	for (uint8_t i=0; i<2; ++i)
	{
		// write the SROM file (=firmware data)
		cs_select(i);
		uint8_t data = SROM_Load_Burst | 0x80;	// write burst destination adress
		pio_spi_write8_blocking(&sensors[i].spi, &data, 1);
		sleep_us(15);

		// send all bytes of the firmware
		for (int j = 0; j < firmware_length; j++) {
			pio_spi_write8_blocking(&sensors[i].spi, &(firmware_data[j]), 1);
			sleep_us(15);
		}

		cs_deselect(i);
	}

	// Read the SROM_ID register to verify the ID before any other register reads or writes.
	// (and discard data)
	uint8_t v[2];
	read_registers(SROM_ID, v);

	// Write 0x00 to Config2 register for wired mouse or 0x20 for wireless mouse design.
	write_register(Config2, 0x00);

	// set initial CPI resolution
	write_register(Config1, 0x15);
}

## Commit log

2024-09-18 Initial commit (before conversion from builder mode to algebra mode)
    [Pico-R3.step, rp2040-pmw3360.step]
2024-09-19 Make use for @ operator when defining button sketch.
2024-09-21 Add buttons
2024-09-22 Add basic bottom plate.
2024-09-22 Add and place button switch PCBs
2024-09-22 Add screw holes for button pcbs.
2024-09-23 Replace pipico STEP with schematic
2024-09-23 Add mount points for Pico Pi.
2024-09-23 Add top/bottom notches and opening for USB cable.
2024-09-24 Add mount points for sensor PCBs.
2024-09-25 Button hinge assembly (WIP)
2024-09-28 Add top/bottom alignment notches for center hole.
2024-09-29 Button hinge assembly (WIP2)
2024-09-29 Add attachment points for buttons.
2024-09-30 Add screwholes connecting top & bottom.
2024-10-01 Separate button pad from button hinge/spring assembly.
2024-10-01 Update sensor PCB distances and hole geometry.
2024-10-01 Add basic README. Check in generated STLs (and remove STEP file).
    [ball.stl, bottom.stl, button0.stl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]
2024-10-01 Remove STEP file.
    [Pico-R3.step]
2024-10-06 Add notches on underside of buttons as stabilizers.
    [button0.stl, button1.stl, button2.stl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]
2024-10-07 Make button strips thinner (as experiment)
    Also make hole alignment notch thinner.
    [strip0.stl, strip1.stl, strip2.stl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]
2024-10-20 Add optional holes for ball transport units instead of bearing balls.
    Also added some extra comments.
    [top.stl]
2024-10-20 Optionally generate STEP instead of STL files (depending on cmdline arg).
    Also adds .step version of generated parts to repo.
    [ball.step, bottom.step, button0.step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]
2024-10-22 Adjust bearing hole size again. Also update TODO list.
2024-10-24 Add test file for USB-C mount.
2024-10-26 Add (optional) hole for USB-C plug.
2024-10-27 Add optional logo and pulleys for strips.
    [ball.step, bottom.step, bottom.stl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]
2024-11-02 Add initial set of hacks to get 45 degree sensors to work.
2024-11-02 Add basic SPI PIO if from pico examples to firmware. (not used yet)
2024-11-03 Switch to using PIO SPI for sensor interfaces.
2024-11-04 Create fused PMW3360_pair class.
2024-11-05 Rearrange sensor pins.
2024-11-05 Detect if one of the sensors is unresponsive and restart them.
2024-11-06 Regenerate STEP and STL files
    [ball.step, bottom.step, bottom.stl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]
2024-11-13 Add model for BTU->bearing adapter Remap pins.
    [adapter.step, adapter.stl]
2024-11-24 Final pin/button remapping. Got rid of dead sensor detection.
2024-11-24 Minor cleanup to adapter.py and models.
    [adapter.step, adapter.stl]
2024-12-03 Add strengthening fillets to button strips. Switch to using standalone vscode_ocp for update watcher.
    [ball.step, bottom.step, bottom.stl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]
2025-01-27 Add initial WIP support for Supermini RP2040 board.
2025-01-28 Revising mount points for RP2040 SuperMini board.
2025-02-02 Add mount points for G304 keyswitch PCBs.
2025-02-10 Add pull-out notches to bearing holes. Improve update_watcher script a bit.
2025-02-10 Add extra fastening holes on the sides.
2025-02-23 Add FW support for alternative RP2040-supermini board.
2025-02-27 One screw should be enough to attach strips to buttons.
2025-03-04 Add pull tool for bearings. Some small fixes to update watcher.
2025-03-09 Fix issue with scroll not working after wake-up from suspend.
    [trackball.cc]
2025-09-10 Add USB-C mount for Mk.II
2025-09-14 Add basic button shapes for Mk.II.
2025-10-26 Some progress on Trackball Mk.II buttons.
2025-10-26 Some Mk.II button suspension tweaks.
2025-10-27 Redo Mk.II button suspension.
2025-10-28 Add positioners for keyswitch PCBs.
2025-10-28 Make USB-C plug easier to print without supports.
2025-10-28 Add one more button stabilizer.
2025-11-04 Add counter-flap on bottom of buttons.
2025-11-06 Some tweaks to Mk.II buttons.
2025-11-17 Add screwholes. Add switches to turn off features for faster regeneration.
2025-11-18 Fix missing PCB attachment points.
2025-11-23 Reduce button tension to 0.25mm.
2025-12-25 Add release generator script and remove prebuilt STEP/STL files (use tarballs instead).
    [adapter.step, adapter.stl, ball.step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]
2026-01-11 Remove button tension in mk.ii trackball (adjust manually instead). Adjust wrist-rest length. Minor fix to README.
2026-01-24 Add option to print front of buttons in a separate color filament in Mk.II Fix issue with magnet cutout in wrist-rest not being deep enough.
2026-01-25 Add a few extra layers for button fronts (so the color doesn't shine through). Adjust button tension to give more leeway.
2026-05-13 Improved clamp for MCU PCB.
